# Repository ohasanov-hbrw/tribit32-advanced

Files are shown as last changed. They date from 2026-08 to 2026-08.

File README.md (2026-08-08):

# tribit32-advanced

A tri-microcontroller, overengineered GameBoy Advance clone. More value was given to the controls and the exterior look, which is cool!

## Introduction

This guide is more about the software side of the project. The 3D-Designs and the KiCad files can be found in their respective folders and be edited as needed. This project is as open source as I can make it to be, so if something is missing, message me and I will try to add it here. It would still like builds using this guide to mention me and link to this guide, so thanks in advance!

## Electronics

This section includes information about the electronics I used for the project. This project can be built in three ways: just a single board computer, just the microcontroller, or both at once. Doing both increases difficulty exponentially, so it is not really recommended and is more of a showpiece. 

### Microcontrollers and Single Board Computers

The custom PCB is laid out for an ESP32-S3-DevkitC and Raspberry Pi Zero 2W. If you can make alternatives work with adapters / custom software, you can use that too. However this project focuses more on these two specific boards. 

If you are going to be including a Raspberry Pi, you will also need to get an Arduino Pro Mini for the controller emulation. 

### Periphery

- **ILI9341 3.2inch *non-touch* SPI LCD**: 320x240 16 Bit Color, rated for 10 MHz SPI but most comfortably can run at ~67 MHz. ST7789 might work, but definitely not tested.
- **MAX98357A I2S DAC**: A pretty ok DAC + Amplifier combo. PCM5102 might work too, but these modules are cheap anyway.
- **Micro SD Adapter**: Only needed for ESP32. 
- **2x 4 ohm 20x30 mm Speakers**: Connected in series they enable rich sound.

### Power

- **5 V / 3.3 V Regulators**: Please do not use LDOs or linear regulators. These are inneficient. If just running the Raspberry Pi you can technically forego the 3.3 V Regulator and just use a 5 V one, as the Pi already has (a weak) one on board. Or even better? Use an MH-CD42 Li-Ion charger module with the onboard regulator. Less parts mean less things to solder!
- **Li-Ion Charger**: I originally used a TP4056 which did technically work fine, but after finishing the project I found out better alternatives exist that dont really have that much difference in price. Just get an MH-CD42!
### Other Components

- **6 mm Silicone Buttons**: You can also use different alternatives, the PCB should be able to support them with minimal modifications to the buttons.
- **100 ohm, 10 kohm and 100 kohm Resistors**: Values are actually not that important, something in the ballpark should work. Used mainly for pullups, resistor divider for battery monitoring...
- **Wires**: Use what you have...
- **2.54 mm male and female headers**: You can also totally do the project without any female or even any headers, but you can make pretty much everything dissasemble-able using these. 
- **BC547 NPN Transistors**: Really only needed if you are building a two-board system. 

### PCB

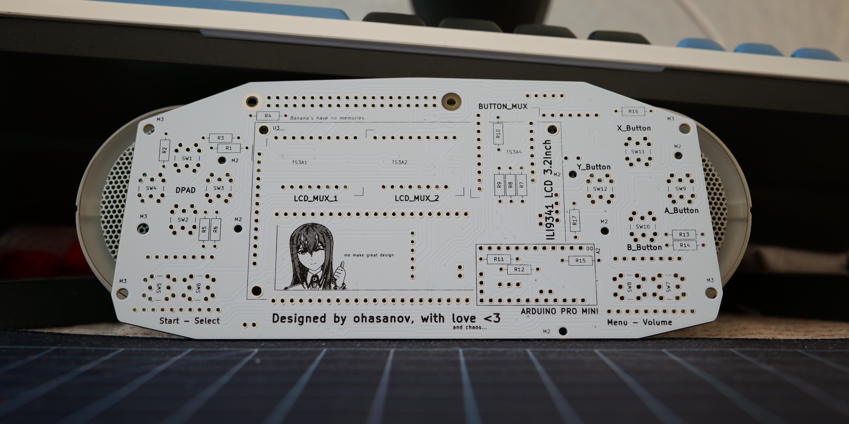
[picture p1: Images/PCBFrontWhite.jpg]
PCB Front Side

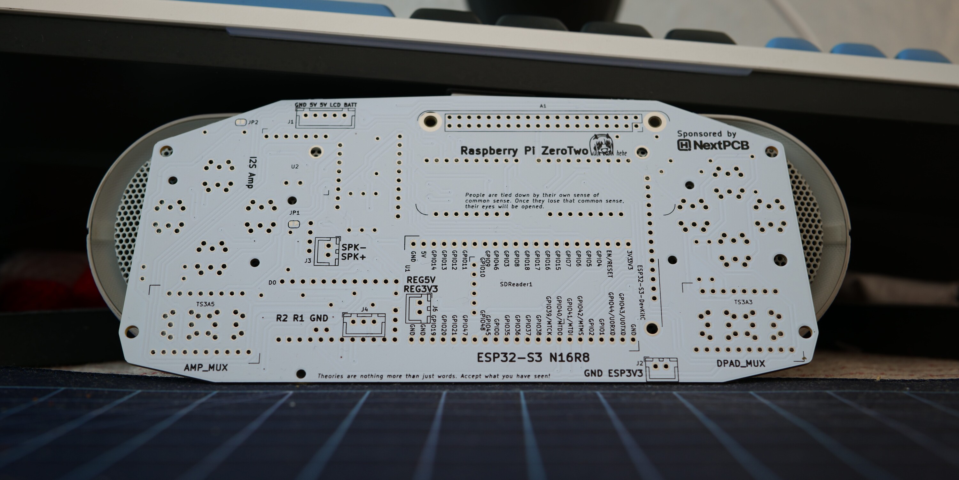
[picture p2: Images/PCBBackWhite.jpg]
PCB Back Side


This project is mainly thought out to be built with a custom PCB. Although it is technically possible to make this with normal perfboards as all used components are through hole components (no SMD components), a PCB makes the assembly process a lot faster whilst also resulting in a cleaner build. 

The PCBs for my build were manufactured by [NextPCB](https://www.nextpcb.com/). Thanks a lot for them sending over the PCBs and thus motivating me to design my own PCBs for my future projects. 

## Software Guide

This section will be divided into two subsections. Software for the ESP32 and Software for the Raspberry Pi

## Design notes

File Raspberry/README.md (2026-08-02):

# Raspberry Pi Software Setup

This folder has everything I did to a basic Raspbian OS Lite Bookworm instal to make it work with the console. Check out the individual folders for more information.

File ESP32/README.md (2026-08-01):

# retro-go
Just check https://github.com/ducalex/retro-go for installation. The guide there is good.

My config for the target esp32-s3-devkit is in this folder. There is also a compiled image, but IDK how effective that is.

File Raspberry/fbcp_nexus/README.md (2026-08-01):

# Modifications

This was also forked from [Original Modified Repo](https://github.com/The-Next-Guy/fbcp-nexus/). This fork has some modifications to fit better with my gameboy build. Modified by ohasanov.

## Original Repo

This was forked from the [Original Repo](https://github.com/juj/fbcp-ili9341). Some of the original README.md was modified. I preserved building informations, but removed stats and FAQ. To see the original information, go to the original repo. This repository implements a driver for certain SPI-based LCD displays for Raspberry Pi A, B, 2, 3, 4 and Zero. Modified by The_Next_Guy

### Tested Devices

The driver has been checked to work (at least some point in the past) on the following systems:

 - Raspberry Pi 3 Model B+ with Raspbian Stretch (GCC 6.3.0)
 - Raspberry Pi 3 Model B Rev 1.2 with Raspbian Jessie (GCC 4.9.2) and Raspbian Stretch (GCC 6.3.0)
 - Raspberry Pi Zero W with Raspbian Jessie (GCC 4.9.2) and Raspbian Stretch (GCC 6.3.0)
 - Raspberry Pi 2 Model B
 - Raspberry Pi B Rev. 2.0 (old board from Q4 2012, board revision ID 000e)
 - Raspberry Pi Zero W 2 with RetroPie

### Installation

Check the following sections to set up the driver.

##### Boot configuration

This driver does not utilize the [notro/fbtft](https://github.com/notro/fbtft) framebuffer driver, so that needs to be disabled if active. That is, if your `/boot/config.txt` file has lines that look something like `dtoverlay=pitft28r, ...`, `dtoverlay=waveshare32b, ...` or `dtoverlay=flexfb, ...`, those should be removed.

This program neither utilizes the default SPI driver, so a line such as `dtparam=spi=on` in `/boot/config.txt` should also be removed so that it will not cause conflicts.

Likewise, if you have any touch controller related dtoverlays active, such as `dtoverlay=ads7846,...` or anything that has a `penirq=` directive, those should be removed as well to avoid conflicts. It would be possible to add touch support to fbcp-ili9341 if someone wants to take a stab at it.

##### Building and running

Run in the console of your Raspberry Pi:

```bash
sudo apt-get install cmake
cd ~
git clone https://github.com/The-Next-Guy/fbcp-nexus.git
cd fbcp-nexus
mkdir build
cd build
cmake [options] ..
make -j
sudo ./fbcp-ili9341
```

Note especially the two dots `..` on the CMake line, which denote "up one directory" in this case (instead of referring to "more items go here").

See the next section to see what to input under **[options]**.

If you have been running existing `fbcp` driver, make sure to remove that e.g. via a `sudo pkill fbcp` first (while running in SSH prompt or connected to a HDMI display), these two cannot run at the same time. If `/etc/rc.local` or `/etc/init.d` contains an entry to start up `fbcp` at boot, that directive should be deleted.

##### Configuring build options

There are generally two ways to configure build options, at CMake command line, and in the file [config.h](https://github.com/juj/fbcp-ili9341/blob/master/config.h).

On the CMake command line, the following options can be configured:

###### If you have a display Add-On Hat

When using one of the displays that stack on top of the Pi that are already recognized by fbcp-ili9341, you don't need to specify the GPIO pin assignments, but fbcp-ili9341 code already has those. Pass one of the following CMake directives for the hats:

- `-DADAFRUIT_ILI9341_PITFT=ON`: If you are running on the [Adafruit 2.8" 320x240 TFT w/ Touch screen for Raspberry Pi](https://www.adafruit.com/product/1601) (or the [Adafruit PiTFT 2.2" HAT Mini Kit - 320x240 2.2" TFT - No Touch](https://www.adafruit.com/product/2315) display, which is compatible), pass this flag.
- `-DADAFRUIT_HX8357D_PITFT=ON`: If you have the [Adafruit PiTFT - Assembled 480x320 3.5" TFT+Touchscreen for Raspberry Pi](https://www.adafruit.com/product/2097) display, add this line.
- `-DFREEPLAYTECH_WAVESHARE32B=ON`: If you are running on the [Freeplay CM3 or Zero](https://www.freeplaytech.com/product/freeplay-cm3-diy-kit/) device, pass this flag. (this is not a hat, but still a preconfigured pin assignment)
- `-DWAVESHARE35B_ILI9486=ON`: If specified, targets a [Waveshare 3.5" 480x320 ILI9486](https://www.amazon.co.uk/dp/B01N48NOXI/ref=pe_3187911_185740111_TE_item) display.
- `-DTONTEC_MZ61581=ON`: If you are running on the [Tontec 3.5" 320x480 LCD Display](https://www.ebay.com/p/Tontec-3-5-Inches-Touch-Screen-for-Raspberry-Pi-Display-TFT-Monitor-480x320-LCD/1649448059) display, pass this.
- `-DPIRATE_AUDIO_ST7789_HAT=ON`: If specified, targets a [Pirate Audio 240x240, 1.3inch IPS LCD display HAT for Raspberry Pi](https://shop.pimoroni.com/collections/pirate-audio) with ST7789 display controller
- `-DWAVESHARE_ST7789VW_HAT=ON`: If specified, targets a [240x240, 1.3inch IPS LCD display HAT for Raspberry Pi](https://www.waveshare.com/1.3inch-lcd-hat.htm) with ST7789VW display controller.
- `-DWAVESHARE_ST7735S_HAT=ON`: If specified, targets a [128x128, 1.44inch LCD display HAT for Raspberry Pi](https://www.waveshare.com/1.3inch-lcd-hat.htm) with ST7735S display controller.
- `-DKEDEI_V63_MPI3501=ON`: If specified, targets a [KeDei 3.5 inch SPI TFTLCD 480*320 16bit/18bit version 6.3 2018/4/9](https://github.com/juj/fbcp-ili9341/issues/40) display with MPI3501 display controller.

###### If you wired the display to the Pi yourself

If you connected wires directly on the Pi instead of using a Hat from the above list, you will need to use the configuration directives below. In addition to specifying the display, you will also need to tell fbcp-ili9341 which GPIO pins you wired the connections to. To configure the display controller, pass one of:

- `-DILI9341=ON`: If you are running on any other generic ILI9341 display, or on Waveshare32b display that is standalone and not on the FreeplayTech CM3/Zero device, pass this flag.
- `-DILI9340=ON`: If you have a ILI9340 display, pass this directive. ILI9340 and ILI9341 chipsets are very similar, but ILI9340 doesn't support all of the features on ILI9341 and they will be disabled or downgraded.
- `-DHX8357D=ON`: If you have a HX8357D display, pass this directive.
- `-DSSD1351=ON`: If you have a SSD1351 OLED display, use this.
- `-DST7735R=ON`: If you have a ST7735R display, use this.
- `-DST7789=ON`: If you have a ST7789 display, use this.
- `-DST7789VW=ON`: If you have a ST7789VW display, use this.
- `-DST7735S=ON`: If you have a ST7735S display, use this.
- `-DILI9486=ON`: If you have a ILI9486 display, pass this directive.
- `-DILI9486L=ON`: If you have a ILI9486L display, pass this directive. Note that ILI9486 and ILI9486L are quite different, mutually incompatible controller chips, so be careful here identifying which one you have. (or just try both, should not break if you misidentified)
- `-DILI9488=ON`: If you have a ILI9488 display, pass this directive.
- `-DMPI3501=ON`: If specified, targets a display with MPI3501 display controller.

And additionally, pass the following to customize the GPIO pin assignments you used:

- `-DGPIO_TFT_DATA_CONTROL=number`: Specifies/overrides which GPIO pin to use for the Data/Control (DC) line on the 4-wire SPI communication. This pin number is specified in BCM pin numbers. If you have a 3-wire SPI display that does not have a Data/Control line, **set this value to -1**, i.e. `-DGPIO_TFT_DATA_CONTROL=-1` to tell fbcp-ili9341 to target 3-wire ("9-bit") SPI communication.
- `-DGPIO_TFT_RESET_PIN=number`: Specifies/overrides which GPIO pin to use for the display Reset line. This pin number is specified in BCM pin numbers. If omitted, it is assumed that the display does not have a Reset pin, and is always on.
- `-DGPIO_TFT_BACKLIGHT=number`: Specifies/overrides which GPIO pin to use for the display backlight line. This pin number is specified in BCM pin numbers. If omitted, it is assumed that the display does not have a GPIO-controlled backlight pin, and is always on. If setting this, also see the `#define BACKLIGHT_CONTROL` option in `config.h`.

fbcp-ili9341 always uses the hardware SPI0 port, so the MISO, MOSI, CLK and CE0 pins are always the same and cannot be changed. The MISO pin is actually not used (at the moment at least), so you can just skip connecting that one. If your display is a rogue one that ignores the chip enable line, you can omit connecting that as well, or might also be able to get away by connecting that to ground if you are hard pressed to simplify wiring (depending on the display).

###### Specifying display speed

To get good performance out of the displays, you will drive the displays far out above the rated speed specs (the rated specs yield about ~10fps depending on display). Due to this, you will need to explicitly configure the target speed you want to drive the display at, because due to manufacturing variances each display copy reaches a different maximum speed. There is no "default speed" that fbcp-ili9341 would use. Setting the speed is done via the option

- `-DSPI_BUS_CLOCK_DIVISOR=even_number`: Sets the clock divisor number which along with the Pi [core_freq=](https://www.raspberrypi.org/documentation/configuration/config-txt/overclocking.md) option in `/boot/config.txt` specifies the overall speed that the display SPI communication bus is driven at. `SPI_frequency = core_freq/divisor`. `SPI_BUS_CLOCK_DIVISOR` must be an even number. Default Pi 3B and Zero W `core_freq` is 400MHz, and generally a value `-DSPI_BUS_CLOCK_DIVISOR=6` seems to be the best that a ILI9341 display can do. Try a larger value if the display shows corrupt output, or a smaller value to get higher bandwidth. See [ili9341.h](https://github.com/juj/fbcp-ili9341/blob/master/ili9341.h#L13) and [waveshare35b.h](https://github.com/juj/fbcp-ili9341/blob/master/waveshare35b.h#L10) for data points on tuning the maximum SPI performance. Safe initial value could be something like `-DSPI_BUS_CLOCK_DIVISOR=30`.

###### Specifying the target Pi hardware

There are a couple of options to explicitly say which Pi board you want to target. These should be autodetected for you and generally are not needed, but e.g. if you are cross compiling for another Pi board from another system, or want to be explicit, you can try:

- `-DSINGLE_CORE_BOARD=ON`: Pass this option if you are running on a Pi that has only one hardware thread (Pi Model A, Pi Model B, Compute Module 1, Pi Zero/Zero W). If not present, autodetected.
- `-DARMV6Z=ON`: Pass this option to specifically optimize for ARMv6Z instruction set (Pi 1A, 1A+, 1B, 1B+, Zero, Zero W). If not present, autodetected.
- `-DARMV7A=ON`: Pass this option to specifically optimize for ARMv7-A instruction set (Pi 2B < rev 1.2). If not present, autodetected.
- `-DARMV8A=ON`: Pass this option to specifically optimize for ARMv8-A instruction set (Pi 2B >= rev. 1.2, 3B, 3B+, CM3, CM3 lite, 4B, CM4, Pi400). If not present, autodetected.

###### Specifying other build options

The following build options are general to all displays and Pi boards, they further customize the build:

- `-DBACKLIGHT_CONTROL=ON`: If set, enables fbcp-ili9341 to control the display backlight in the given backlight pin. The display will go to sleep after a period of inactivity on the screen. If not, backlight is not touched.
- `-DDISPLAY_CROPPED_INSTEAD_OF_SCALING=ON`: If set, and source video frame is larger than the SPI display video resolution, the source video is presented on the SPI display by cropping out parts of it in all directions, instead of scaling to fit.
- `-DDISPLAY_BREAK_ASPECT_RATIO_WHEN_SCALING=ON`: When scaling source video to SPI display, scaling is performed by default following aspect ratio, adding letterboxes/pillarboxes as needed. If this is set, the stretching is performed breaking aspect ratio.
- `-DSTATISTICS=number`: Specifies the level of overlay statistics to show on screen. 0: disabled, 1: enabled, 2: enabled, and show frame rate interval graph as well. Default value is 1 (enabled).
- `-DUSE_DMA_TRANSFERS=OFF`: If specified, disables using DMA transfers (at great expense of lost CPU usage). Pass this directive if DMA is giving some issues, e.g. as a troubleshooting step if something is not looking right.
- `-DDMA_TX_CHANNEL=<num>`: Specifies the DMA channel number to use for SPI send commands. Change this if you find a DMA channel conflict.
- `-DDMA_RX_CHANNEL=<num>`: Specifies the DMA channel number to use for SPI receive commands. Change this if you find a DMA channel conflict.
- `-DDISPLAY_SWAP_BGR=ON`: If this option is passed, red and blue color channels are reversed (RGB<->BGR) swap. Some displays have an opposite color panel subpixel layout that the display controller does not automatically account for, so define this if blue and red are mixed up.
- `-DDISPLAY_INVERT_COLORS=ON`: If this option is passed, pixel color value interpretation is reversed (white=0, black=31/63). Default: black=0, white=31/63. Pass this option if the display image looks like a color negative of the actual colors.
- `-DDISPLAY_ROTATE_180_DEGREES=ON`: If set, display is rotated 180 degrees. This does not affect HDMI output, only the SPI display output.
- `-DLOW_BATTERY_PIN=<num>`: Specifies a GPIO pin that can be polled to get the battery state. By default, when this is set, a low battery icon will be displayed if the pin is pulled low (see `config.h` for ways in which this can be tweaked).

###### New Build Options
- TODO

In addition to the above CMake directives, there are various defines scattered around the codebase, mostly in [config.h](https://github.com/juj/fbcp-ili9341/blob/master/config.h), that control different runtime options. Edit those directly to further tune the behavior of the program. In particular, after you have finished with the setup, you may want to build with `-DSTATISTICS=0` option in CMake configuration line.

##### Build example

Here is a full example of what to type to build and run, if you have the [Adafruit 2.8" 320x240 TFT w/ Touch screen for Raspberry Pi](https://www.adafruit.com/product/1601) with ILI9341 controller:

```bash
cd ~
sudo apt-get install cmake
git clone https://github.com/The-Next-Guy/fbcp-nexus.git
cd fbcp-nexus
mkdir build
cd build
cmake -DSPI_BUS_CLOCK_DIVISOR=6 -DADAFRUIT_ILI9341_PITFT=ON ..
make -j
sudo ./fbcp-ili9341
```

If the above does not work, try specifying `-DSPI_BUS_CLOCK_DIVISOR=8` or `=10` to make the display run a little slower, or try with `-DUSE_DMA_TRANSFERS=OFF` to troubleshoot if DMA might be the issue. If you are using another display controller than ILI9341, using a much higher value, like 30 or 40 may be needed. When changing CMake options, you can reissue the CMake directive line without having to reclone or recreate the `build` directory. However you may need to manually delete file CMakeCache.txt between changing options to avoid CMake remembering old settings.

If you want to do a full rebuild from scratch, you can `rm -rf build` to delete the build directory and recreate it for a clean rebuild from scratch. There is nothing special about the name or location of this directory, it is just my usual convention. You can also do the build in some other directory relative to the fbcp-ili9341 directory if you please.

### Extra Info

Best way to discuss the driver is to open a GitHub issue. The-Next-Guy will be monitoring any new things that pop up, pull requests, bugs, and fixes. Since this still runs just fine for RetroPie, I think its still worth maintaining. For FAQ, Tuning and more information, please check out the [Original Repo](https://github.com/juj/fbcp-ili9341).

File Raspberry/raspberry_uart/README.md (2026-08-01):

# Raspberry-UART-Controller
An uinput controller driver for the Raspberry Pi, that interfaces with an Arduino Pro Mini over the native serial port. Also draws overlays with https://github.com/The-Next-Guy/fbcp-nexus/ If something doesn't work, delete the contents of `config.prop` and rerun the software from the terminal. This starts the setup process.

### Changes made
This is a version of the whole thing that is meant to be run with a Arduino Pro mini as the Serial slave device. Instead of using axis data for the dpad, just using buttons made more sense to me. Additionally, at least the button mapping was a bit weird, which I (ohasanov) changed to suit my needs.

A (south), B (east), X (west), Y (north) is used for layout.
There are two buttons named Extra and Options. Extra is supposed to be the hotkey button for Retropie/Retroarch. Options is thought out for the whole overlay thing the original creator of this repo coded in. 

### Hotkeys (changeable under joyCheck in main.cpp):

Options + A + L + R for a sec -> reboot

Options + B + L + R for a sec -> shutdown

Options + X + L + R for a sec -> restart fbcp service

Options + B -> Battery

Options + X -> Volume (with DPAD UP DOWN to change)

Options + Y -> Brightness (with DPAD UP DOWN to change)

### Thanks
Thanks to The-Next-Guy for creating the original repo, check out https://github.com/The-Next-Guy/picotroller

### Compiling
This program requires `libevdev-dev` to be installed, which can be simply installed with
```
sudo apt-get install libevdev-dev
```

It also requires lodepng.h and lodepng.cpp to be dropped in next to the rest of the source. Ensure the SMA IDs in `shared_memory.h` are the same as the ones set in fbcp-nexus. Create a `config.prop` file next to the source, or else it will throw an error. This is also meant to be ran as a privileged app. 

To build the project, you can just run:
```
make
sudo ./joystick_emulator
```
This will take you through the setup, choose the pico monitor as the other one might be broken after my changes to the code. You can write your own too, by extending Monitor in Monitor.h. You will have to modify the main file to add the option.

If you choose the pico monitor, it will it up and strat running right away on `/dev/serial0` but you can change this by changing the `interface` property.

Once the monitor is setup, it will ask you to setup the buttons, depending on the features provided by the monitor.

Lastly, it will ask you to setup the audio device that it will be using, just enter it like it is. It could be `PCM`, `Headphone`, `HDMI`, or something else.

This whole setup can be ran from ssh, without a keyboard, provided that you have your pico or gpio pins wired up. Who knows, maybe you'll make a wifi client.

To make it start on boot, edit `/etc/rc.local` and add
```
sudo /path/to/pictroller/joystick_emulator&
```

or better yet, maybe create a systemd command to run this on startup?

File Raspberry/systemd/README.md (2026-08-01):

# SystemD Services
These files go to `/etc/systemd/system/` and are there to autostart the controller emulator and the fbcp driver. You might need to change the location of the binaries, as they are configured for my username.

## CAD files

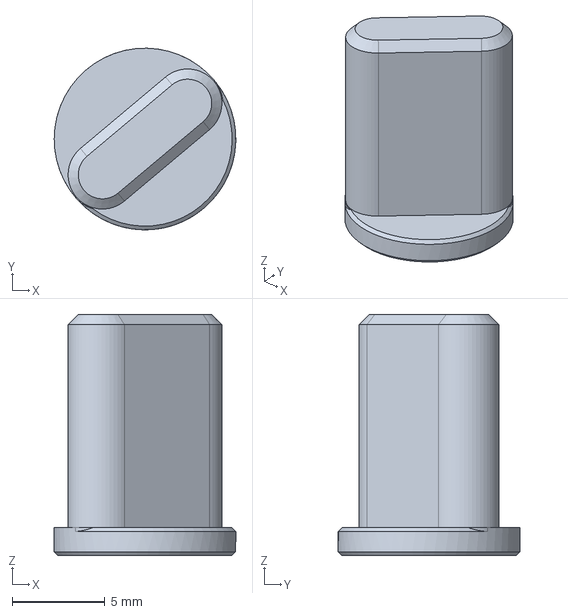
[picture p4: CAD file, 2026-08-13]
3D Files/Option Button.step
9.80 x 9.80 x 13.0 mm

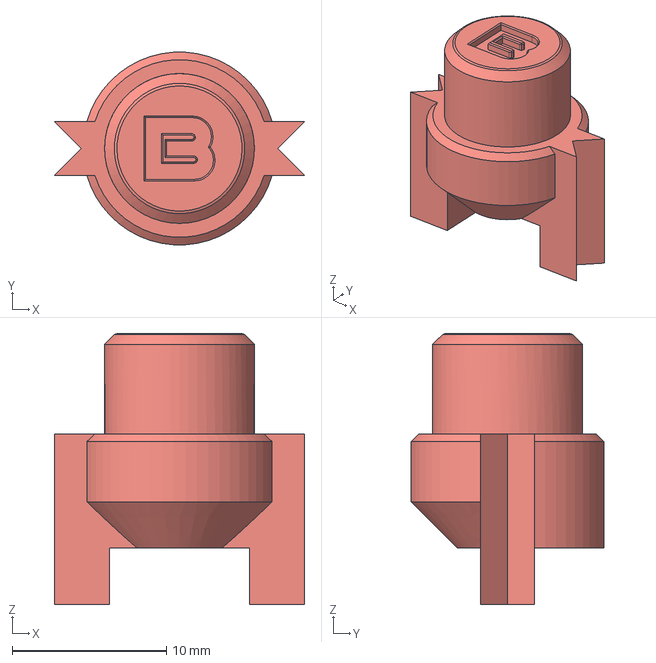
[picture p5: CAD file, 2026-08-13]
3D Files/Face Button B.step
16.2 x 12.5 x 17.6 mm

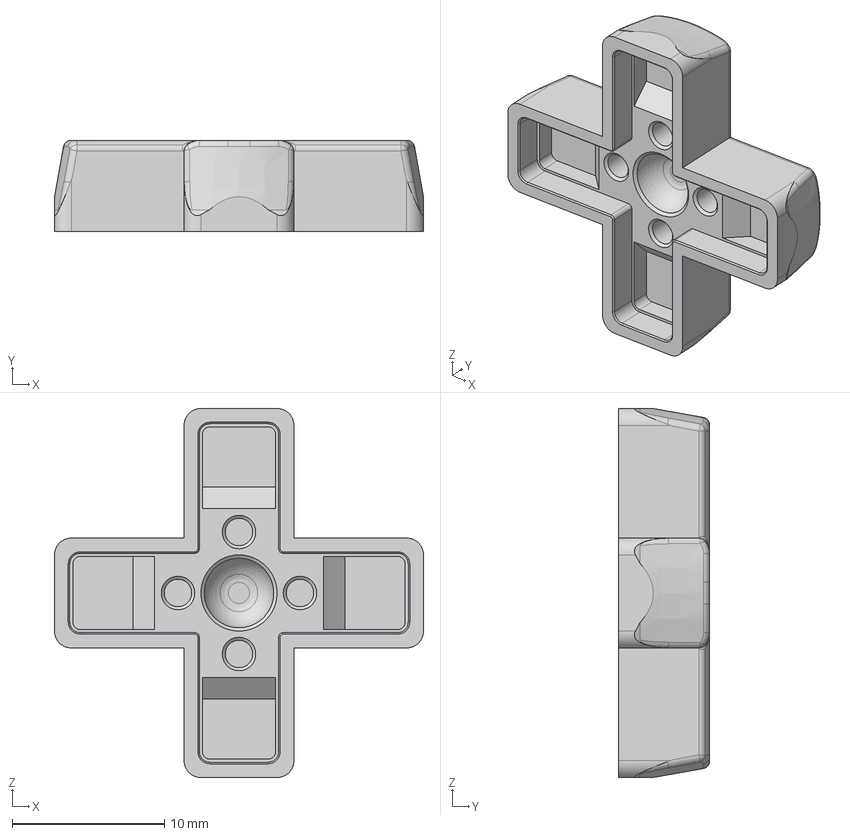
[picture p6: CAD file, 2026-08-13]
3D Files/DPADBodyTop.step
24.2 x 6.00 x 24.2 mm

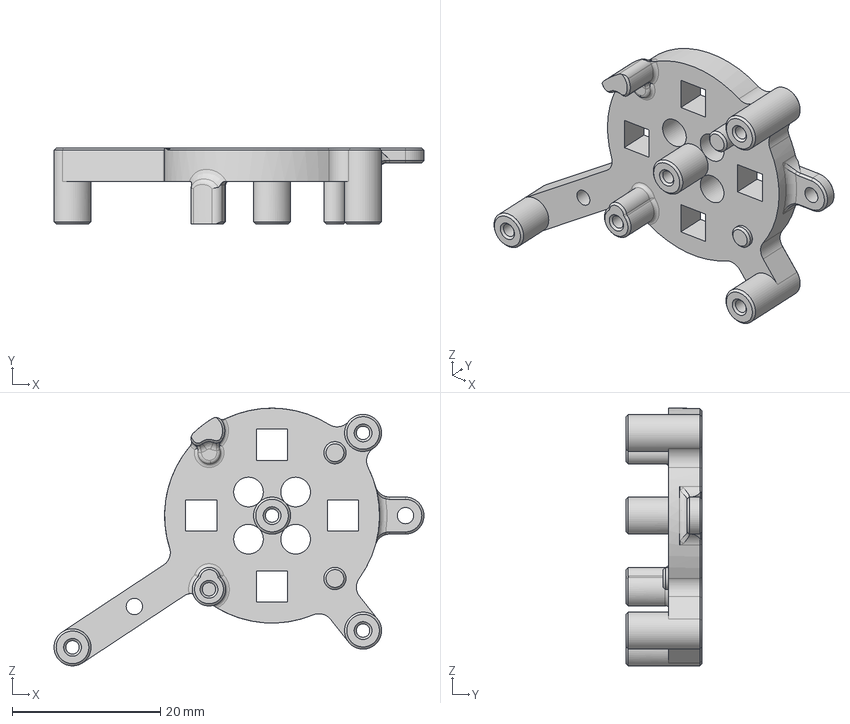
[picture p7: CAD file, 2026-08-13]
3D Files/DPADSpacer.step
49.9 x 10.3 x 34.8 mm

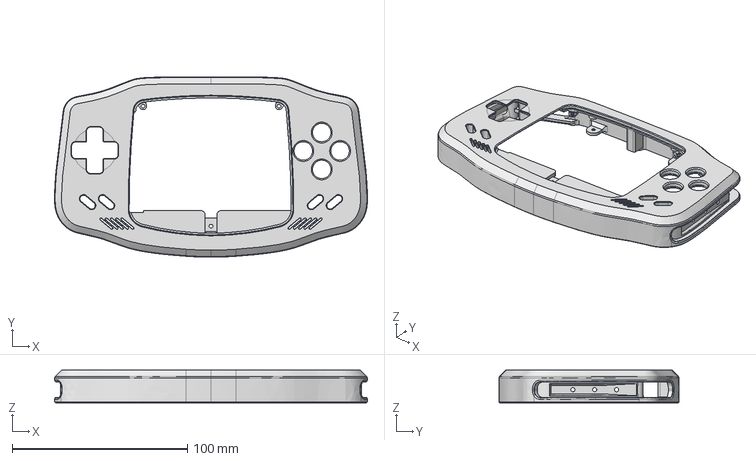
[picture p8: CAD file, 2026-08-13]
3D Files/Top Shell.step
178.5 x 102.8 x 18.7 mm

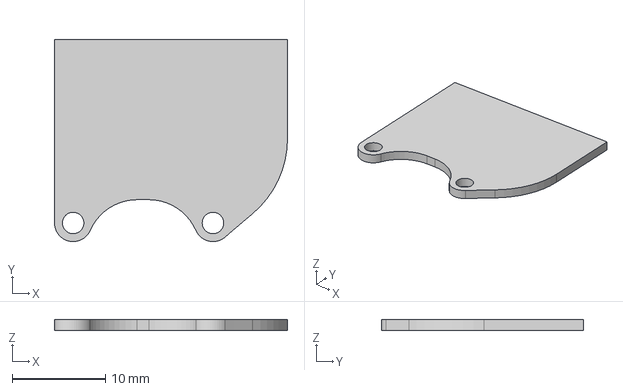
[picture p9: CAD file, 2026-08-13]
3D Files/MH-CD Holder.step
25.0 x 21.7 x 1.20 mm

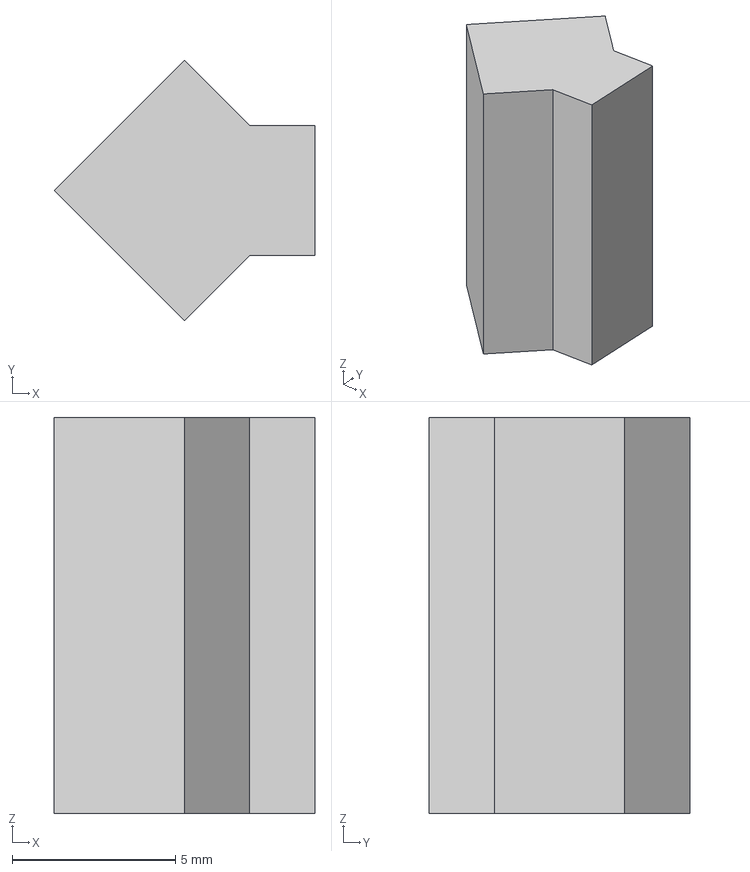
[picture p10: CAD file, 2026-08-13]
3D Files/Face Button Post Short.step
8.00 x 8.00 x 12.1 mm

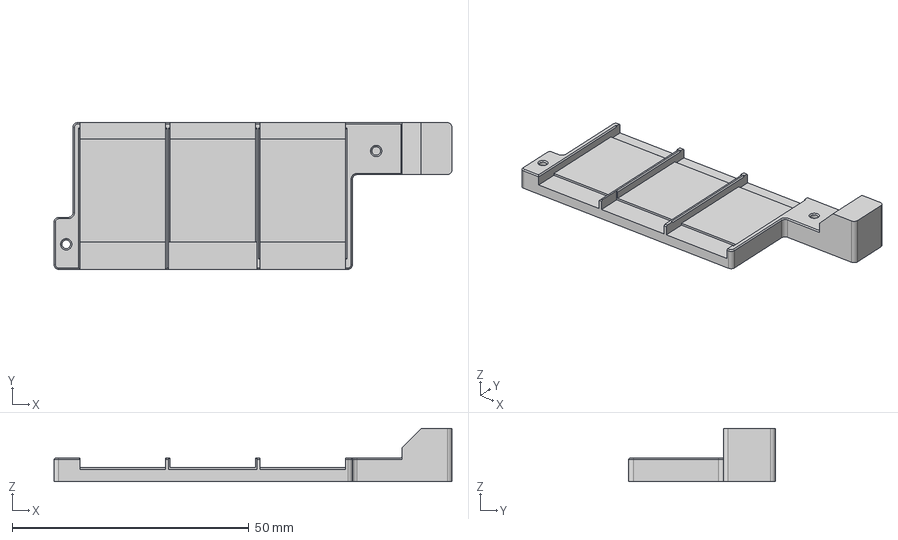
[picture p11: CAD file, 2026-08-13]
3D Files/TPS Holder Bottom.step
84.0 x 31.0 x 11.2 mm

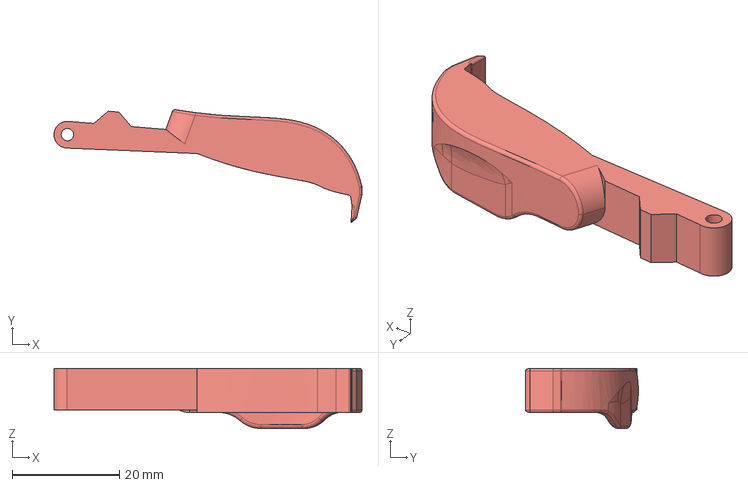
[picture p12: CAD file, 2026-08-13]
3D Files/Shoulder Button (also mirrored).step
57.3 x 21.0 x 11.2 mm

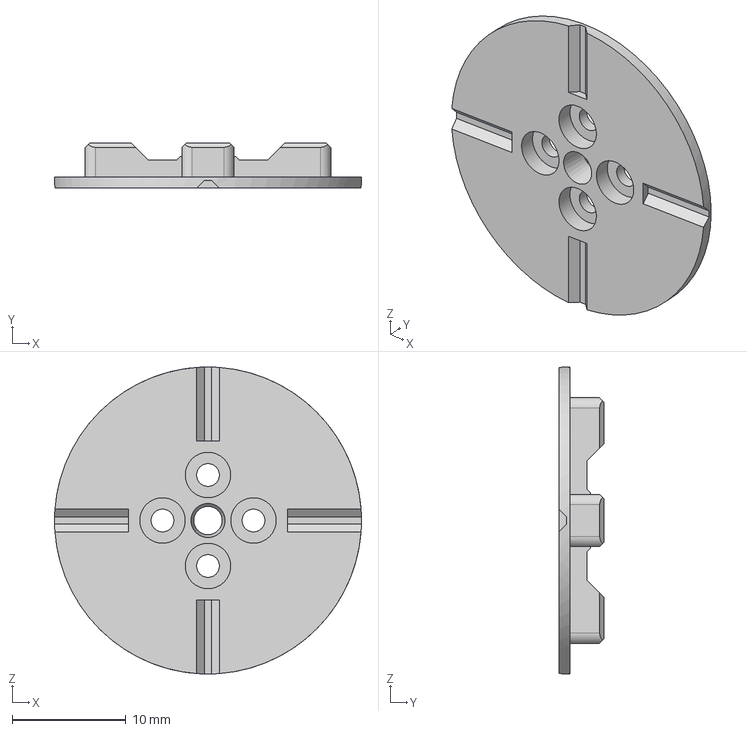
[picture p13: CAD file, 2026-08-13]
3D Files/DPADBody.step
27.0 x 4.00 x 27.0 mm

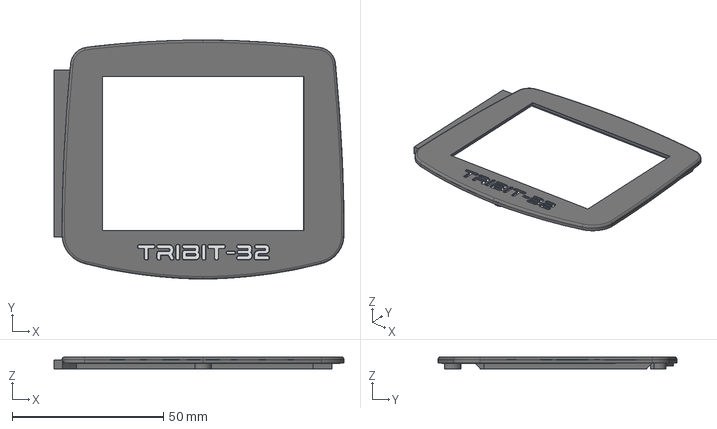
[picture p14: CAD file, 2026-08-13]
3D Files/Screen Frame.step
95.9 x 79.1 x 4.06 mm

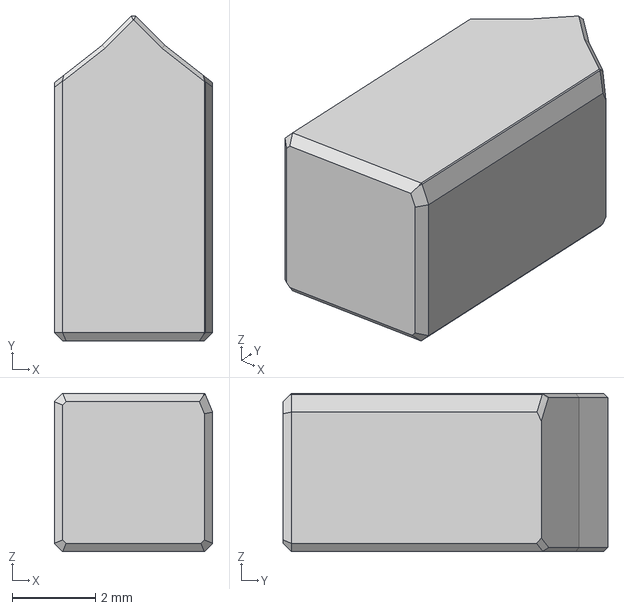
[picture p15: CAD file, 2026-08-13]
3D Files/DPADPin.step
3.80 x 7.80 x 3.80 mm

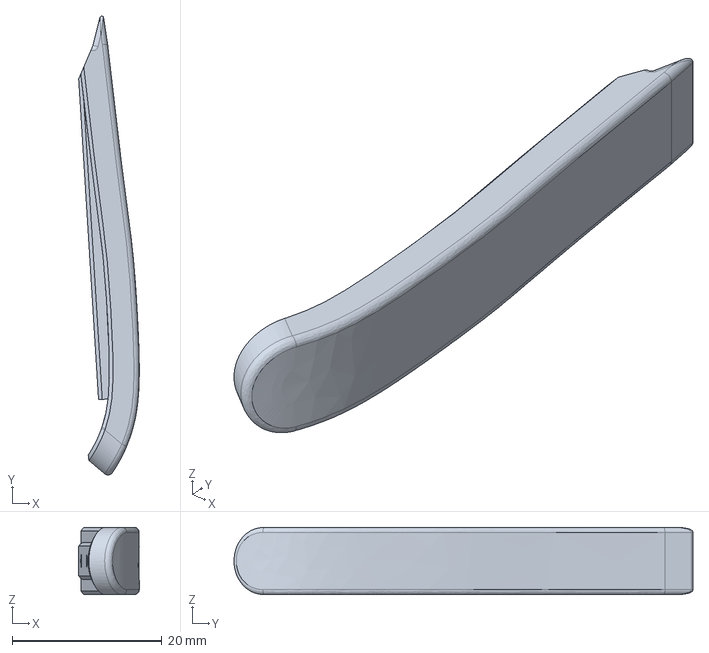
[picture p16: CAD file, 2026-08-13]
3D Files/Side Plastic (also mirrored).step
8.09 x 61.2 x 9.00 mm

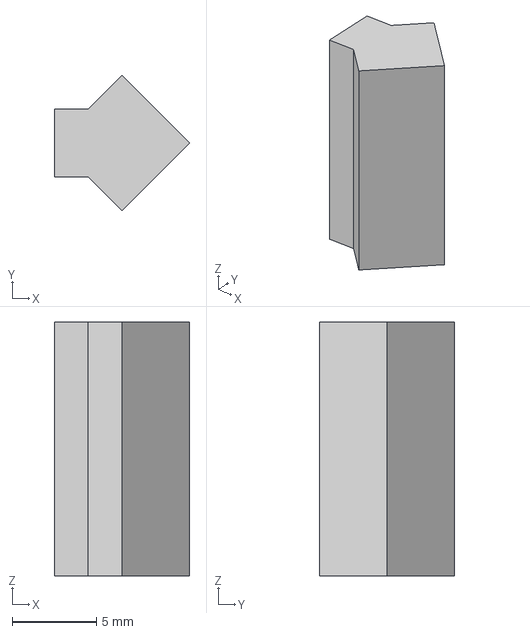
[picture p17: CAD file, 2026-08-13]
3D Files/Face Button Post Long.step
8.00 x 8.00 x 15.1 mm

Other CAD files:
3D Files/Face Button X.step
3D Files/Face Button A.step
3D Files/Top Shell Flat.stl
3D Files/TPS Holder Lid.step
3D Files/Face Button Structure.step
3D Files/Face Button Y.step
3D Files/Speaker Lid (also mirrored).step
3D Files/Switch Holder.step
3D Files/TP4056 Holder.step

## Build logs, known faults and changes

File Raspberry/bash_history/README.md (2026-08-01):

# Bash History
This is literally the complete list of commands I used for setting this up. Sadly selections for the menus are not there but it should still give an idea... More about backing up stuff than anything.

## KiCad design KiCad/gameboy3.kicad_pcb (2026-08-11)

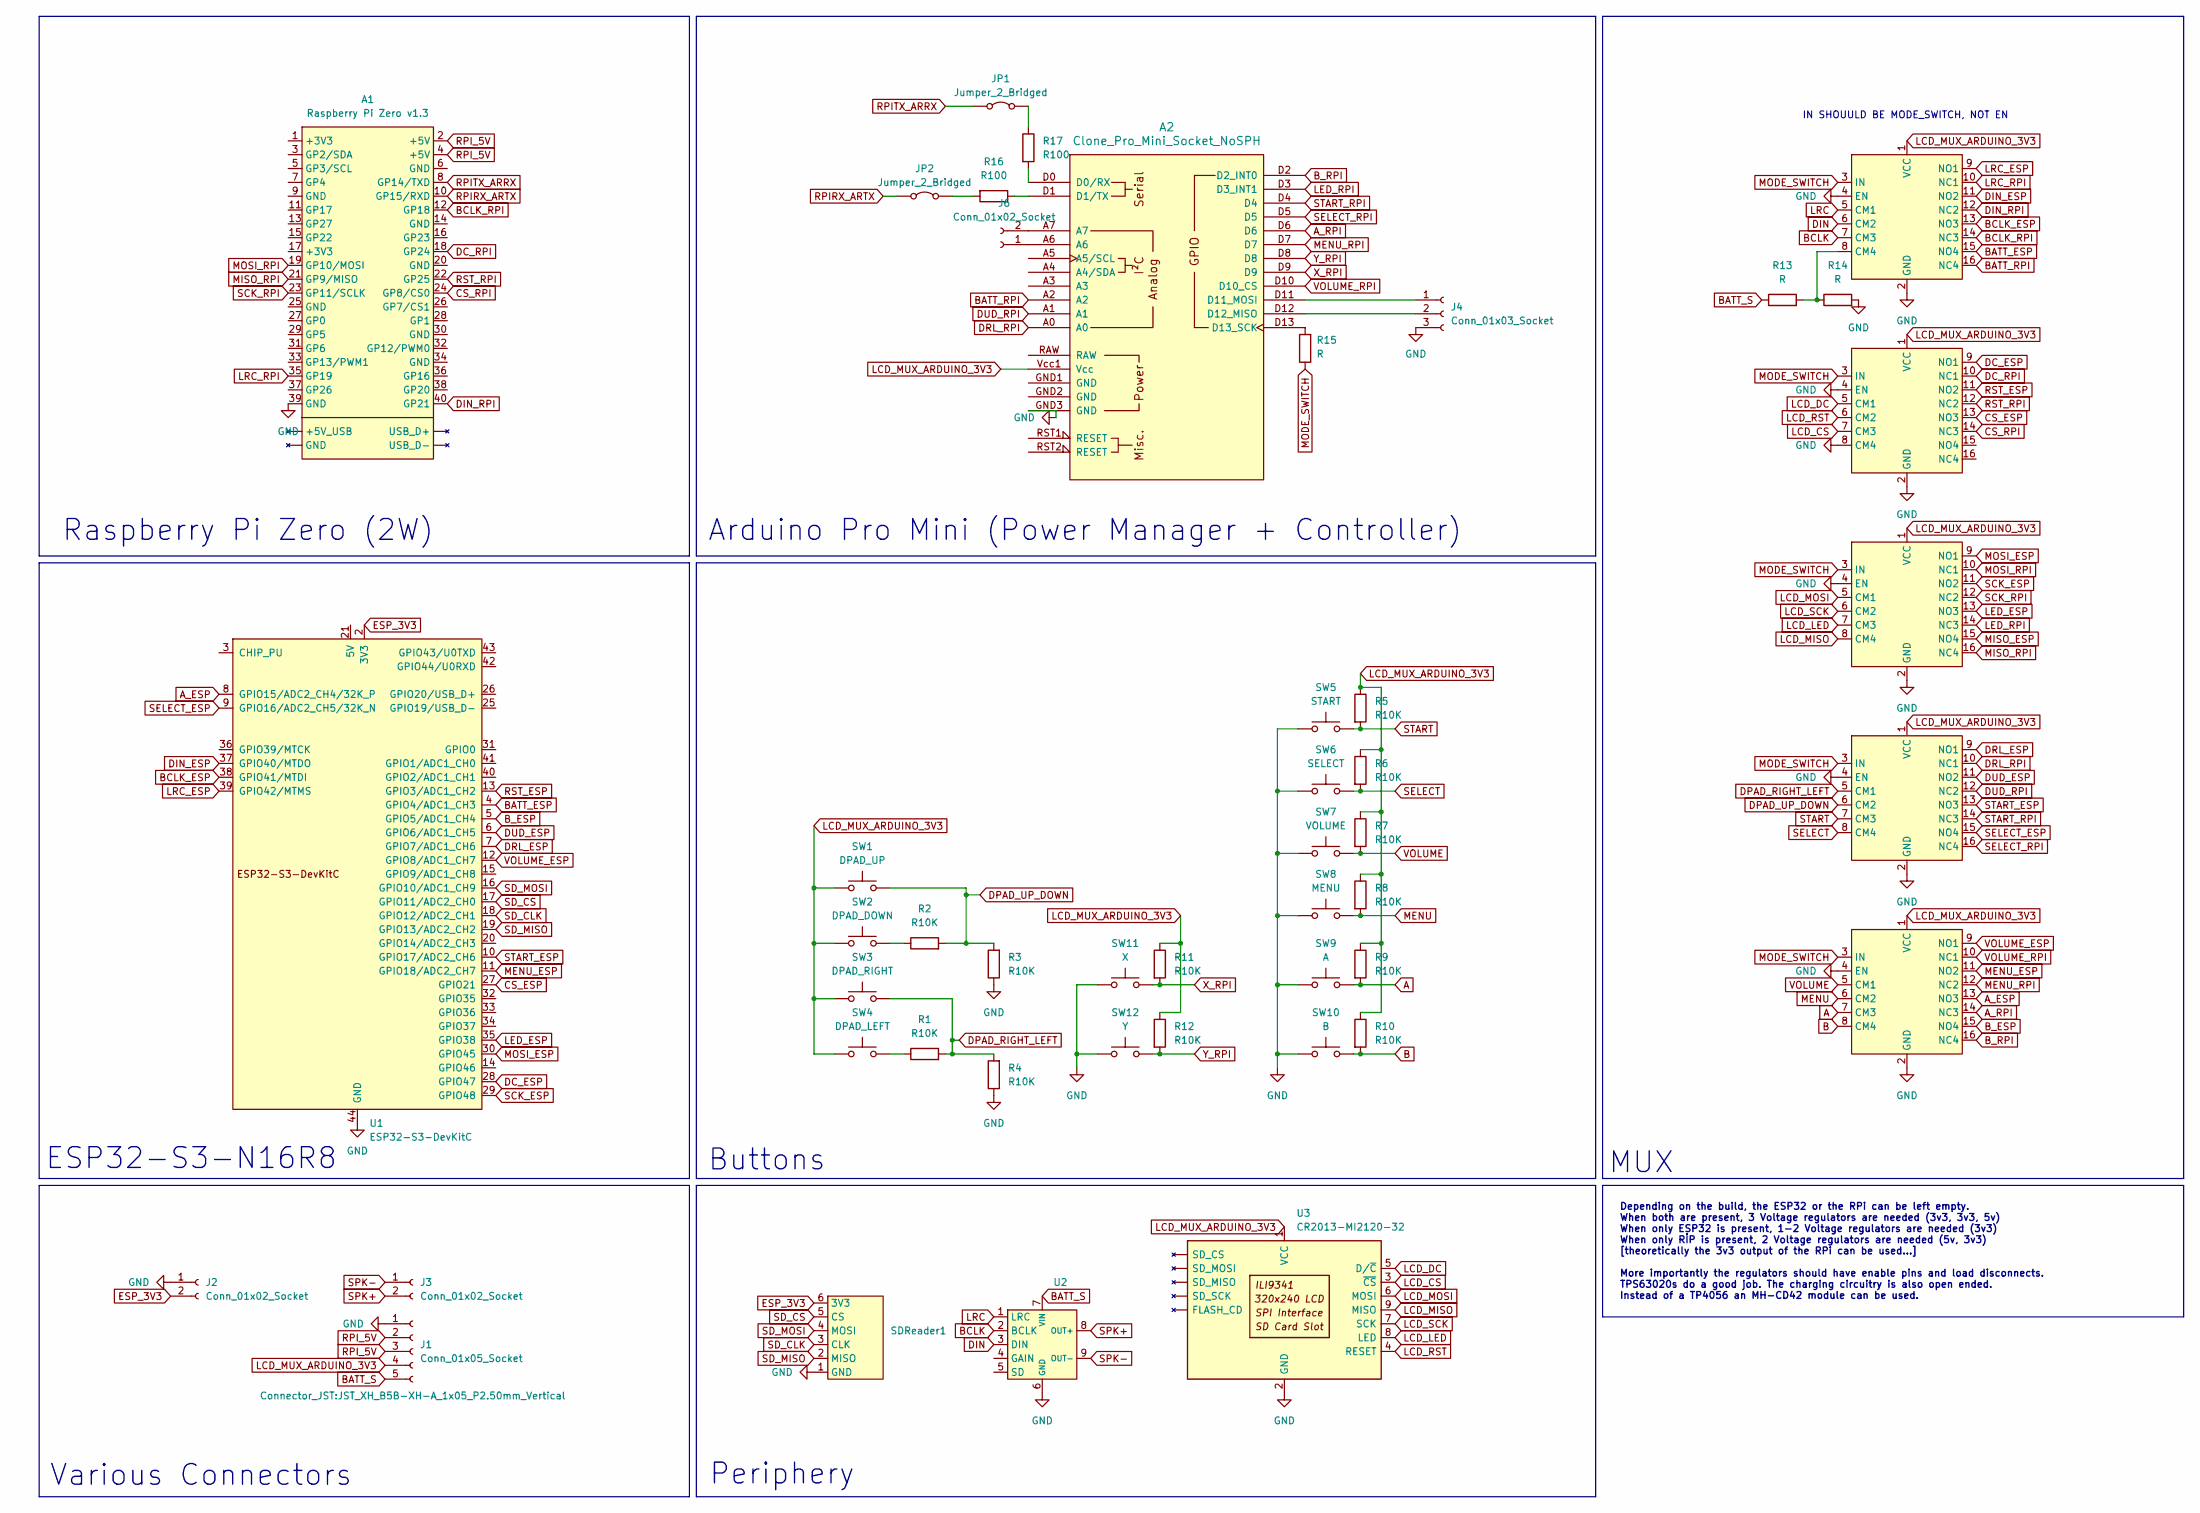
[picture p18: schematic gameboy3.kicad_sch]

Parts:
A1: Raspberry Pi Zero v1.3; Raspberry_Pi_Zero
A2: Clone_Pro_Mini_Socket_NoSPH
J1: Conn_01x05_Socket; JST_XH_B5B-XH-A_1x05_P2.50mm_Vertical
J2, J3, J6: Conn_01x02_Socket; JST_XH_B2B-XH-A_1x02_P2.50mm_Vertical
J4: Conn_01x03_Socket; JST_XH_B3B-XH-A_1x03_P2.50mm_Vertical
JP1, JP2: Jumper_2_Bridged; SolderJumper-2_P1.3mm_Open_RoundedPad1.0x1.5mm
R1, R2, R3, R4, R5, R6, R7, R8, R9, R10, R11, R12: R10K; R_Axial_DIN0207_L6.3mm_D2.5mm_P10.16mm_Horizontal
R13, R14, R15: R; R_Axial_DIN0207_L6.3mm_D2.5mm_P10.16mm_Horizontal
R16, R17: R100; R_Axial_DIN0207_L6.3mm_D2.5mm_P10.16mm_Horizontal
SDReader1: SDReader
SW1: DPAD_UP; PUSH_BUTTON
SW2: DPAD_DOWN; PUSH_BUTTON
SW3: DPAD_RIGHT; PUSH_BUTTON
SW4: DPAD_LEFT; PUSH_BUTTON
SW5: START; PUSH_BUTTON
SW6: SELECT; PUSH_BUTTON
SW7: VOLUME; PUSH_BUTTON
SW8: MENU; PUSH_BUTTON
SW9: A; PUSH_BUTTON
SW10: B; PUSH_BUTTON
SW11: X; PUSH_BUTTON
SW12: Y; PUSH_BUTTON
TS3A1, TS3A2, TS3A3, TS3A4, TS3A5: TS3A5018_Module
U1: ESP32-S3-DevKitC
U2: MAX_I2S
U3: CR2013-MI2120-32

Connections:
A: R9.2, SW9.2, TS3A4.7 (CM3)
A_ESP: TS3A4.13 (NO3), U1.8 (GPIO15/ADC2_CH4/32K_P)
A_RPI: A2.D6, TS3A4.14 (NC3)
B: R10.2, SW10.2, TS3A4.8 (CM4)
BATT_ESP: TS3A5.15 (NO4), U1.4 (GPIO4/ADC1_CH3)
BATT_RPI: A2.A2, TS3A5.16 (NC4)
BATT_S: J1.5, R13.1, U2.7 (VIN)
BCLK: TS3A5.7 (CM3), U2.2 (BCLK)
BCLK_ESP: TS3A5.13 (NO3), U1.38 (GPIO41/MTDI)
BCLK_RPI: A1.12 (GP18), TS3A5.14 (NC3)
B_ESP: TS3A4.15 (NO4), U1.5 (GPIO5/ADC1_CH4)
B_RPI: A2.D2 (D2_INT0), TS3A4.16 (NC4)
CS_ESP: TS3A2.13 (NO3), U1.27 (GPIO21)
CS_RPI: A1.24 (GP8/CS0), TS3A2.14 (NC3)
DC_ESP: TS3A2.9 (NO1), U1.28 (GPIO47)
DC_RPI: A1.18 (GP24), TS3A2.10 (NC1)
DIN: TS3A5.6 (CM2), U2.3 (DIN)
DIN_ESP: TS3A5.11 (NO2), U1.37 (GPIO40/MTDO)
DIN_RPI: A1.40 (GP21), TS3A5.12 (NC2)
DPAD_RIGHT_LEFT: R1.2, R4.2, SW3.2, TS3A3.5 (CM1)
DPAD_UP_DOWN: R2.2, R3.2, SW1.2, TS3A3.6 (CM2)
DRL_ESP: TS3A3.9 (NO1), U1.7 (GPIO7/ADC1_CH6)
DRL_RPI: A2.A0, TS3A3.10 (NC1)
DUD_ESP: TS3A3.11 (NO2), U1.6 (GPIO6/ADC1_CH5)
DUD_RPI: A2.A1, TS3A3.12 (NC2)
ESP_3V3: J2.2, SDReader1.6 (3V3), U1.1 (3V3), U1.2 (3V3)
GND: A1.39 (GND), A2.GND3 (GND), J1.1, J2.1, J4.3, R3.1, R4.1, R14.2, SDReader1.1 (GND), SW5.1, SW6.1, SW7.1, SW8.1, SW9.1, SW10.1, SW11.1, SW12.1, TS3A1.2 (GND), TS3A1.4 (EN), TS3A2.2 (GND), TS3A2.4 (EN), TS3A2.8 (CM4), TS3A3.2 (GND), TS3A3.4 (EN), TS3A4.2 (GND), TS3A4.4 (EN), TS3A5.2 (GND), TS3A5.4 (EN), U1.22 (GND), U1.23 (GND), U1.24 (GND), U1.44 (GND), U2.6 (GND), U3.2 (GND)
LCD_CS: TS3A2.7 (CM3), U3.3 (~CS)
LCD_DC: TS3A2.5 (CM1), U3.5 (D/~C)
LCD_LED: TS3A1.7 (CM3), U3.8 (LED)
LCD_MISO: TS3A1.8 (CM4), U3.9 (MISO)
LCD_MOSI: TS3A1.5 (CM1), U3.6 (MOSI)
LCD_MUX_ARDUINO_3V3: A2.Vcc1 (Vcc), J1.4, R5.1, R6.1, R7.1, R8.1, R9.1, R10.1, R11.1, R12.1, SW1.1, SW2.1, SW3.1, SW4.1, TS3A1.1 (VCC), TS3A2.1 (VCC), TS3A3.1 (VCC), TS3A4.1 (VCC), TS3A5.1 (VCC), U3.1 (VCC)
LCD_RST: TS3A2.6 (CM2), U3.4 (RESET)
LCD_SCK: TS3A1.6 (CM2), U3.7 (SCK)
LED_ESP: TS3A1.13 (NO3), U1.35 (GPIO38)
LED_RPI: A2.D3 (D3_INT1), TS3A1.14 (NC3)
LRC: TS3A5.5 (CM1), U2.1 (LRC)
LRC_ESP: TS3A5.9 (NO1), U1.39 (GPIO42/MTMS)
LRC_RPI: A1.35 (GP19), TS3A5.10 (NC1)
MENU: R8.2, SW8.2, TS3A4.6 (CM2)
MENU_ESP: TS3A4.11 (NO2), U1.11 (GPIO18/ADC2_CH7)
MENU_RPI: A2.D7, TS3A4.12 (NC2)
MISO_ESP: TS3A1.15 (NO4)
MISO_RPI: A1.21 (GP9/MISO), TS3A1.16 (NC4)
MODE_SWITCH: R15.1, TS3A1.3 (IN), TS3A2.3 (IN), TS3A3.3 (IN), TS3A4.3 (IN), TS3A5.3 (IN)
MOSI_ESP: TS3A1.9 (NO1), U1.30 (GPIO45)
MOSI_RPI: A1.19 (GP10/MOSI), TS3A1.10 (NC1)
unnamed: A2.D0 (D0/RX), R17.2
unnamed: A2.D1 (D1/TX), R16.1
unnamed: A2.D11 (D11_MOSI), J4.1
unnamed: A2.D12 (D12_MISO), J4.2
unnamed: A2.D13 (D13_SCK), R15.2
unnamed: A2.A6, J6.1
unnamed: A2.A7, J6.2
unnamed: JP1.2 (B), R17.1
unnamed: JP2.2 (B), R16.2
unnamed: R1.1, SW4.2
unnamed: R2.1, SW2.2
unnamed: R13.2, R14.1, TS3A5.8 (CM4)
RPIRX_ARTX: A1.10 (GP15/RXD), JP2.1 (A)
RPITX_ARRX: A1.8 (GP14/TXD), JP1.1 (A)
RPI_5V: A1.2 (+5V), A1.4 (+5V), J1.2, J1.3
RST_ESP: TS3A2.11 (NO2), U1.13 (GPIO3/ADC1_CH2)
RST_RPI: A1.22 (GP25), TS3A2.12 (NC2)
SCK_ESP: TS3A1.11 (NO2), U1.29 (GPIO48)
SCK_RPI: A1.23 (GP11/SCLK), TS3A1.12 (NC2)
SD_CLK: SDReader1.3 (CLK), U1.18 (GPIO12/ADC2_CH1)
SD_CS: SDReader1.5 (CS), U1.17 (GPIO11/ADC2_CH0)
SD_MISO: SDReader1.2 (MISO), U1.19 (GPIO13/ADC2_CH2)
SD_MOSI: SDReader1.4 (MOSI), U1.16 (GPIO10/ADC1_CH9)
SELECT: R6.2, SW6.2, TS3A3.8 (CM4)
SELECT_ESP: TS3A3.15 (NO4), U1.9 (GPIO16/ADC2_CH5/32K_N)
SELECT_RPI: A2.D5, TS3A3.16 (NC4)
SPK+: J3.2, U2.8 (OUT+)
SPK-: J3.1, U2.9 (OUT-)
START: R5.2, SW5.2, TS3A3.7 (CM3)
START_ESP: TS3A3.13 (NO3), U1.10 (GPIO17/ADC2_CH6)
START_RPI: A2.D4, TS3A3.14 (NC3)
VOLUME: R7.2, SW7.2, TS3A4.5 (CM1)
VOLUME_ESP: TS3A4.9 (NO1), U1.12 (GPIO8/ADC1_CH7)
VOLUME_RPI: A2.D10 (D10_CS), TS3A4.10 (NC1)
X_RPI: A2.D9, R11.2, SW11.2
Y_RPI: A2.D8, R12.2, SW12.2

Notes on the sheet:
Depending on the build, the ESP32 or the RPi can be left empty. When both are present, 3 Voltage regulators are needed (3v3, 3v3, 5v) When only ESP32 is present, 1-2 Voltage regulators are needed (3v3) When only RİP is present, 2 Voltage regulators are needed (5v, 3v3) [theoretically the 3v3 output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
Various Connectors
Periphery
Buttons
IN SHOUULD BE MODE_SWITCH, NOT EN
ESP32-S3-N16R8
Raspberry Pi Zero (2W)
Arduino Pro Mini (Power Manager + Controller)
MUX

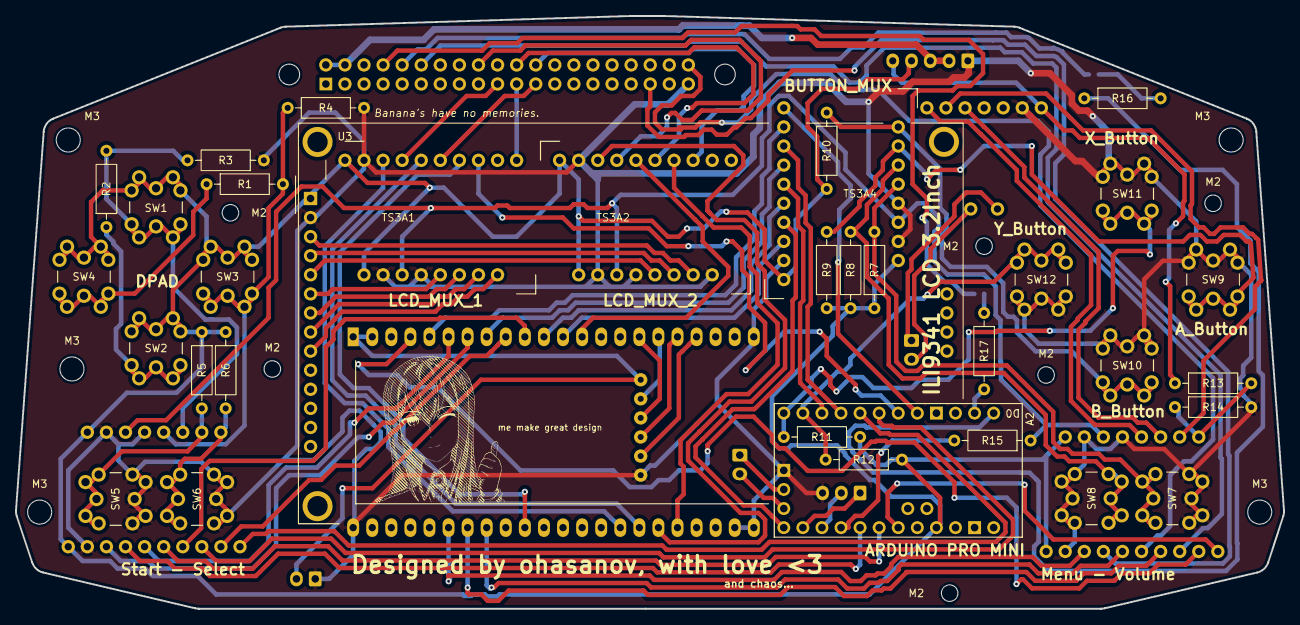
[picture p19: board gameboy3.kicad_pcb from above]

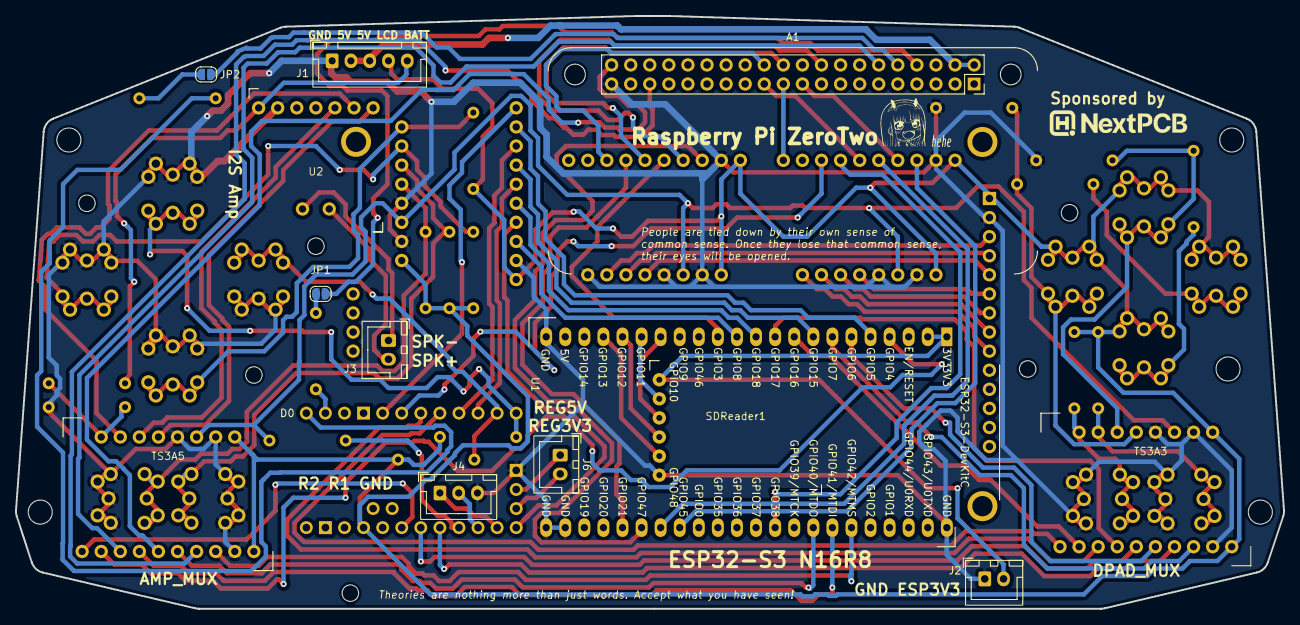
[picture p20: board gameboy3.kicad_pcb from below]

Board: 2 copper layers, 168.8 x 78.9 mm, 61 parts (15 on the bottom side), 83 nets.

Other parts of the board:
M2, M2#2, M2#3, M2#4, M2#5, M2#6: MountingHole_2.2mm_M2_DIN965
M3, M3#2, M3#3, M3#4, M3#5: MountingHole_3.2mm_M3_DIN965
Sponsored by: LOGO
hehe: LOGO
me make great design: LOGO

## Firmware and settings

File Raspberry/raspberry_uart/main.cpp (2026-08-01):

#include <iostream>
#include <cstdio>
#include <thread>
#include <fcntl.h>
#include <unistd.h>
#include <libgen.h>
#include <cstring>
#include <string>
#include <sys/reboot.h>

#include "overlay.h"
#include "pico_monitor.h"
#include "gpio_monitor.h"
#include "controller.h"
#include "GPIO.h"
#include "properties.h"

#define VERSION "0.1"

#define OVERLAY_TIMEOUT 5
#define STATUS_TIMEOUT 10
#define FAN_MIN_VALUE 125

#define FAN_STEP_SIZE 5
#define BACK_STEP_SIZE 5

#define AXIS_DEADZONE 100
#define RESISTOR_RATIO 2
#define VREF_ADC 3.3
#define VOFF 0.1

#define OVERLAY_BATTERY 0
#define OVERLAY_BRIGHTNESS 4
#define OVERLAY_FAN 2
#define OVERLAY_VOLUME 1
#define OVERLAY_CLOSED -1

#define DEBUG_GPIO_OVERLAY false

using String = std::string;

int VOLUME_STEP_SIZE = 1, VOLUME_MIN = 0, VOLUME_MAX = 1;
int SELECT_BUTTON, START_BUTTON, L_BUTTON, R_BUTTON, A_BUTTON, B_BUTTON, X_BUTTON, Y_BUTTON, EXTRA_BUTTON, OPTIONS_BUTTON , DPAD_UP, DPAD_DOWN, DPAD_LEFT, DPAD_RIGHT;
bool joyCheck(ControllerData[], int);
std::string getLocalFile(const std::string& filename);

Monitor* monitor = nullptr;
ControllerManager manager(joyCheck);
OverlayManager overlay;
GPIO gpio;

volatile int overlay_counter = 0, fanCounter = 0, special_counter = 0;
int last_vol, overlay_id = -1, overlay_dir;
std::string audDevice;

void controllerLoop() {
    manager.loop();
}

void picoProcess(int data) {
	std::cout << "Battery Value: " << manager.batteryValue << std::endl;
}

float batt_diffs[11] = {4.05, 4.00, 3.95, 3.92, 3.87, 3.82, 3.79, 3.75, 3.72, 3.65, 3.20};
int   batt_percs[11] = {100, 90, 80, 70, 60, 50, 40, 30, 20, 10, 1};

int getBatteryPercentage(float voltage) {
	int perc = 0;
	int diff_index = 0;
    for(int i = 0; i < 11; i++) {
		if(voltage > batt_diffs[i]) {
			perc = batt_percs[i];
			diff_index = i;
			break;
		}
	}
	
	if(perc == 0 || perc == 100) return perc;
	
	float delta = (voltage - batt_diffs[diff_index]) / (batt_diffs[diff_index - 1] - batt_diffs[diff_index]);
	perc += (int)(delta * 10);
	
	return perc;
}

void drawVolumeOverlay(int dir, int value) {
	overlay.drawPNG(getLocalFile("assets/overlay_rp.png").c_str(), 0, 0);
	
	float ratio = (float)(value - VOLUME_MIN) / (VOLUME_MAX - VOLUME_MIN);
	float percent = ratio * 100;
	
	if(percent > 70){
		overlay.drawPNG(getLocalFile("assets/volume_full.png").c_str(), 289, 39);
	} else if(percent > 40){
		overlay.drawPNG(getLocalFile("assets/volume_med.png").c_str(), 289, 39);
	}  else if(percent > 1){
		overlay.drawPNG(getLocalFile("assets/volume_low.png").c_str(), 289, 39);
	} else {
		overlay.drawPNG(getLocalFile("assets/volume_mute.png").c_str(), 289, 39);
	}
	
	std::string dStr = std::to_string((int)(percent));
	int xOff = 293;
	
	int strLen = dStr.length();
	if(strLen == 1) xOff += 5;
	if(strLen == 2) xOff += 2;
	
	overlay.drawString(dStr.c_str(), xOff, 190, 0xFFFF, 0xF0);
	
	int h = (118 * ratio);
	
	overlay.drawRect(290, 65, 22, 120, 0xFFFF, 0xFF);
	overlay.fillRect(291, 66 + (118 - h), 20, h, 0xFFFF, 0xFF);
}

void drawFanOverlay(int value, int change) {
	overlay.drawPNG(getLocalFile("assets/overlay_rp.png").c_str(), 0, 0);
	
	fanCounter = (fanCounter+1) % 8;
	int fanFrame = fanCounter;
	
	std::string path = getLocalFile("assets/fan_" + std::to_string(fanFrame) + ".png");
	overlay.drawPNG(path.c_str(), 289, 39);
	
	value -= FAN_MIN_VALUE;
	if(value < 0) value = 0;
	
	float ratio = (float)value / (255 - FAN_MIN_VALUE);
	float percent = ratio * 100;
	
	std::string dStr = std::to_string((int)(percent));
	int xOff = 293;
	
	int strLen = dStr.length();
	if(strLen == 1) xOff += 5;
	if(strLen == 2) xOff += 2;
	
	overlay.drawString(dStr.c_str(), xOff, 190, 0xFFFF, 0xF0);
	
	int h = (118 * ratio);
	
	overlay.drawRect(290, 65, 22, 120, 0xFFFF, 0xFF);
	overlay.fillRect(291, 66 + (118 - h), 20, h, 0xFFFF, 0xFF);
}

void drawBacklightOverlay(int value, int change) {
	overlay.drawPNG(getLocalFile("assets/overlay_rp.png").c_str(), 0, 0);
	
	if(value < 0) value = 0;
	
	float ratio = (float)value / 255;
	float percent = ratio * 100;
	
	if(percent > 75){
		overlay.drawPNG(getLocalFile("assets/brightness_full.png").c_str(), 289, 39);
	} else if(percent > 25){
		overlay.drawPNG(getLocalFile("assets/brightness_half.png").c_str(), 289, 39);
	} else {
		overlay.drawPNG(getLocalFile("assets/brightness_none.png").c_str(), 289, 39);
	}
	
	std::string dStr = std::to_string((int)(percent));
	int xOff = 293;
	
	int strLen = dStr.length();
	if(strLen == 1) xOff += 5;
	if(strLen == 2) xOff += 2;
	
	overlay.drawString(dStr.c_str(), xOff, 190, 0xFFFF, 0xF0);
	
	int h = (118 * ratio);
	
	overlay.drawRect(290, 65, 22, 120, 0xFFFF, 0xFF);
	overlay.fillRect(291, 66 + (118 - h), 20, h, 0xFFFF, 0xFF);
}

float batteryVoltage = 0;

int adcSamples[20] = {0};
int adcSampleIndex = 0;
int adcSampleCount = 0;
int adcTotalSum = 0;

void drawBatteryOverlay(int value) {
	overlay.drawPNG(getLocalFile("assets/battery_overlay.png").c_str(), 0, 0);

        adcTotalSum -= adcSamples[adcSampleIndex];
        adcSamples[adcSampleIndex] = value;
        adcTotalSum += value;

        adcSampleIndex = (adcSampleIndex + 1) % 20;
        if (adcSampleCount < 20) {
            adcSampleCount++;
        }

        float averageValue = (float)adcTotalSum / adcSampleCount;
        float voltage = (((averageValue / (float)1023) * VREF_ADC) + VOFF) * RESISTOR_RATIO;


	//float voltage = (((value / (float)1023) * VREF_ADC) + VOFF) * RESISTOR_RATIO;
	int percent = getBatteryPercentage(voltage);
	batteryVoltage = voltage;
	char buffer[20];
    sprintf(buffer, "%d%% (%.3fv)", percent, voltage);
	
	std::string dStr = std::string(buffer) + (voltage > 4.3 ? " Charging" : " Battery");
	int xOff = (320 - overlay.getStringWidth(dStr.c_str())) / 2;
	//xOff += (3 - dStr.length()) * 3;
	overlay.drawString(dStr.c_str(), xOff, 24, 0xFFFF, 0xFF);
	
	
	int width = (float)232 / 100 * percent;
	overlay.drawRect(43, 2, 234, 16, 0xFFFF, 0xFF);
	overlay.fillRect(44 + (232 - width), 3, width, 14, 0xFFFF, 0xFF);
}

void render_pin_states(){
	int size = 10;
	int xOff = 75;
	int yOff = 20;
	
	overlay.fillRect(320 - (size * 2 + xOff), yOff, size * 2, size * 20, 0xFFFF, 0xFF);
	for(int i = 0; i < 40; i++){
		int x = i < 20 ? 320 - (size * 2 + xOff) : 320 - (size + xOff);
		int y = (i % 20) * size + yOff;
		
		int textX = i < 20 ? 320 - ((size * 8) + xOff - 6) : 320 - (xOff - 1);
		
		bool filled = false;
		bool dir = false;
		bool ioPin = false;
		
		std::string func = "";
		if(HEADER_IO_PINS[i] > 0){
			filled = gpio.readPin(HEADER_IO_PINS[i]);
			dir = gpio.getPinDirection(HEADER_IO_PINS[i]);
		}
		
		int color = 0;
		switch(HEADER_IO_PINS[i]){
			case -4: //DNC Pin
			color = 0xFC00;
			func = "DNC";
			break;
			
			case -3: //5v Pin
			color = 0xFA00;
			func = "5V";
			break;
			
			case -2: //3.3v Pin
			color = 0xF800;
			func = "3V3";
			break;
			
			case -1: //GND Pin
			color = 0x0000;
			func = "GND";
			break;
			
			default: //GND Pin
			color = 0x07E0;
			func = std::to_string(HEADER_IO_PINS[i]);
			ioPin = true;
			break;
		}
		
		if(filled){
			overlay.fillRect(x, y, size, size, color, 0xFF);
		} else {
			overlay.drawRect(x, y, size, size, color, 0xFF);
		}
		while(func.length() < 3) {
			if(i < 20){
				func.insert(0, " ");
			} else {
				func.append(" ");
			}
		}
		
		std::string pinData;
		
		if(ioPin){
			pinData.append(dir ? "Out:" : "In: ");
			pinData.append(filled ? "1" : "0");
		} else {
			pinData.append("     ");
		}
		
		if(i < 20){
			func.append(" ");
			func.append(pinData);
		} else {
			func.insert(0, " ");
			func.insert(0, pinData);
		}
		
		overlay.drawString(func.c_str(), textX, y, 0xFFFF, 0xFF);
	}
}

void controlBrightness(int value) {
	if(value > AXIS_DEADZONE) { //Adjust Down
		manager.monitorRequest(7, manager.backlightValue - BACK_STEP_SIZE);
	} else if(value < -AXIS_DEADZONE) { //Adjust Up
		manager.monitorRequest(7, manager.backlightValue + BACK_STEP_SIZE);
	}
}

void controlFan(int value) {
	if(value > AXIS_DEADZONE) { //Adjust Down
		manager.monitorRequest(5, manager.fanValue - FAN_STEP_SIZE);
	} else if(value < -AXIS_DEADZONE) { //Adjust Up
		manager.monitorRequest(5, manager.fanValue + FAN_STEP_SIZE);
	}
}

std::string removeSubstring(const std::string& str, const std::string& sub) {
    std::string result = str;
    size_t pos;

    // Find the substring in the string and erase it
    while ((pos = result.find(sub)) != std::string::npos) {
        result.erase(pos, sub.length());
    }

    return result;
}

void controlVolume(int value) {
    std::string command;
    if(value < -AXIS_DEADZONE) {
        command = "amixer sset '" + audDevice + "',0 " + std::to_string(VOLUME_STEP_SIZE) + "+";
    } else if(value > AXIS_DEADZONE) {
        command = "amixer sset '" + audDevice + "',0 " + std::to_string(VOLUME_STEP_SIZE) + "-";
    } else {
        command = "amixer sset '" + audDevice + "',0 0+";
    }

    // Execute the command and handle the output
    FILE* pipe = popen(command.c_str(), "r");
    if(!pipe) return;

    char buffer[128];
    std::string result = "";
    while(fgets(buffer, 128, pipe) != NULL) {
        result += buffer;
    }
    pclose(pipe);

	result = removeSubstring(result, "Playback");

	size_t pos = result.find("Limits:");
	if(pos != std::string::npos) {
        std::sscanf(result.c_str() + pos, "Limits: %d - %d", &VOLUME_MIN, &VOLUME_MAX);
    } else {
		
	}
	VOLUME_STEP_SIZE = (VOLUME_MAX - VOLUME_MIN) / 100;
	
    // Parse the output to find the current volume level
    pos = result.find("Front Left:");
    int currVol = 0;
    if(pos != std::string::npos) {
        std::sscanf(result.c_str() + pos, "Front Left: %d", &currVol);
    } else {
		pos = result.find("Mono:");
		if(pos != std::string::npos) {
			std::sscanf(result.c_str() + pos, "Mono: %d", &currVol);
        }
	}
	last_vol = currVol;
}

bool joyCheck(ControllerData controllers[], int c) {
	bool selectPressed = controllers[c].button_states[SELECT_BUTTON];
    bool startPressed  = controllers[c].button_states[START_BUTTON];

	bool optionsPressed = controllers[c].button_states[OPTIONS_BUTTON]; 
	
    bool rPressed      = controllers[c].button_states[R_BUTTON];
    bool lPressed      = controllers[c].button_states[L_BUTTON];
    bool yPressed      = controllers[c].button_states[Y_BUTTON];
    bool xPressed      = controllers[c].button_states[X_BUTTON];
    bool bPressed      = controllers[c].button_states[B_BUTTON];
    bool aPressed      = controllers[c].button_states[A_BUTTON];
	
    int axisValue = 0;
	if(controllers[c].button_states[DPAD_UP]){
		axisValue = -128;
	}
	if(controllers[c].button_states[DPAD_DOWN]){
		axisValue = 128;
	}
	
	
	if(optionsPressed && aPressed && rPressed && lPressed) {
		special_counter++;
		//std::cout << special_counter << std::endl;
		if(special_counter >= 1000) {
			//REBOOT
		    sync(); // Flush filesystem buffers
            std::string command;
			command = "reboot";

			// Execute the command and handle the output
			FILE* pipe = popen(command.c_str(), "r");
			if(pipe){
				char buffer[128];
				while(fgets(buffer, 128, pipe) != NULL) {
				}
				pclose(pipe);
			}
			//reboot(RB_AUTOBOOT);
			exit(0);
		}
		return true;
	} else if(optionsPressed && bPressed && rPressed && lPressed) {
		special_counter++;
		if(special_counter >= 1000) {
	        sync(); // Flush filesystem buffers
            std::string command;
			command = "shutdown -h now";

			// Execute the command and handle the output
			FILE* pipe = popen(command.c_str(), "r");
			if(pipe){
				char buffer[128];
				while(fgets(buffer, 128, pipe) != NULL) {
				}
				pclose(pipe);
			}
			//reboot(RB_POWER_OFF);
			exit(0);
		}
        return true;
	}
	else if(optionsPressed && xPressed && rPressed && lPressed) {
		special_counter++;
		if(special_counter == 1000) {
	        std::string command;
			command = "systemctl restart fbcp";

			// Execute the command and handle the output
			FILE* pipe = popen(command.c_str(), "r");
			if(pipe){
				char buffer[128];
				while(fgets(buffer, 128, pipe) != NULL) {
				}
				pclose(pipe);
			}
		}
        return true;
	}

	
	if(optionsPressed && bPressed) {
		if(special_counter == 0) {
			std::cout << "OVERLAY BATTERY " << manager.getBatteryAverage() << std::endl;
			overlay_id = OVERLAY_BATTERY;
			overlay_counter = 0;
		    special_counter++;
		}
        return true;
	} 
	//else if(selectPressed && aPressed && axisValue != 0) {
	//	int start_delay = 1000;
	//	int cont_delay = 100;
	//	if(special_counter == 1) {
	//		controlFan(axisValue);
	//		overlay_id = 2;
	//		overlay_counter = 0;
	//	}
	//	special_counter++;
	//	if(special_counter == start_delay) {
	//		controlFan(axisValue);
	//		overlay_id = 2;
	//		overlay_counter = 0;
	//	}
	//	if(special_counter >= (start_delay + cont_delay)) {
	//		special_counter = start_delay - 1;
	//	}
    //    return true;
	//} //not using a fan!
	//else if(selectPressed && aPressed) {
	//	if(special_counter == 0) {
	//		overlay_id = 2;
	//		overlay_counter = 0;
	//	}
	//	special_counter = 1;
    //    return true;
	//} 
	else if(optionsPressed && xPressed && axisValue != 0) {
		int start_delay = 1000;
		int cont_delay = 100;
		if(special_counter == 1) {
			std::cout << "OVERLAY VOLUME " << axisValue << std::endl;
			controlVolume(axisValue);
			overlay_id = OVERLAY_VOLUME;
			overlay_counter = 0;
		}
		special_counter++;
		if(special_counter == start_delay) {
			std::cout << "OVERLAY VOLUME " << axisValue << std::endl;
			controlVolume(axisValue);
			overlay_id = OVERLAY_VOLUME;
			overlay_counter = 0;
		}
		if(special_counter >= (start_delay + cont_delay)) {
			special_counter = start_delay - 1;
		}
        return true;
    } else if(optionsPressed && xPressed) {
		if(special_counter == 0) {
			std::cout << "OVERLAY VOLUME " << axisValue << std::endl;
			overlay_id = OVERLAY_VOLUME;
			overlay_counter = 0;
		}
		special_counter = 1;
        return true;
	} else if(optionsPressed && yPressed && axisValue != 0) {
		int start_delay = 1000;
		int cont_delay = 100;
		if(special_counter == 1) {
			std::cout << "OVERLAY BRIGHTNESS " << axisValue << std::endl;
			controlBrightness(axisValue);
			overlay_id = OVERLAY_BRIGHTNESS;
			overlay_counter = 0;
		}
		special_counter++;
		if(special_counter == start_delay) {
			std::cout << "OVERLAY BRIGHTNESS " << axisValue << std::endl;
			controlBrightness(axisValue);
			overlay_id = OVERLAY_BRIGHTNESS;
			overlay_counter = 0;
		}
		if(special_counter >= (start_delay + cont_delay)) {
			special_counter = start_delay - 1;
		}
        return true;
    } else if(optionsPressed && yPressed) {
		if(special_counter == 0) {
			std::cout << "OVERLAY BRIGHTNESS " << axisValue << std::endl;
			overlay_id = OVERLAY_BRIGHTNESS;
			overlay_counter = 0;
		}
		special_counter = 1;
        return true;
	}
	
	special_counter = 0;
	if(optionsPressed){
		return true;
	}
	return false;
}

#define DRAW_LOW_VOLTAGE 1

void drawOverlay(){
	overlay.clearScreen();
	switch(overlay_id){
		case OVERLAY_BATTERY: //Battery
			drawBatteryOverlay(manager.getBatteryAverage());
		    break;
		case OVERLAY_VOLUME: //Volume
			drawVolumeOverlay(0, last_vol);
		    break;
		case OVERLAY_FAN: //Fan
			drawFanOverlay(manager.fanValue, 0);
		    break;
		case OVERLAY_BRIGHTNESS: //Brightness
			drawBacklightOverlay(manager.backlightValue, 0);
		    break;
	}
	if(DRAW_LOW_VOLTAGE && batteryVoltage < 3.4){
		overlay.drawString("LOW VOLTAGE, PLEASE CHARGE", 4, 4, 0x8800, 0xF0);
	}

	if(DEBUG_GPIO_OVERLAY){
		render_pin_states();
	}
	overlay.commit();
}

int strcmp(std::string a, std::string b){
	return strcmp(a.c_str(), b.c_str());
}

#define HOLD_DELAY 100
int holdCounter = 0;
int getHeldPin(int pins[]){
	bool pinStates[25];
	bool search = true;
	int pin = 0, pinIndex = 0;
	holdCounter = 0;
	
	for(int i = 0; i < 25; i++){ //Get initial states
		if(pins[i] == 0) break;
		pinStates[i] = gpio.readPin(pins[i]);
	}
	
	while(search){
		for(int i = 0; i < 25; i++){
			if(pins[i] == 0) break;
			if(pinStates[i] != gpio.readPin(pins[i])){
				pinIndex = i;
				holdCounter++;
				if(holdCounter > HOLD_DELAY){
					pin = pins[i];
					search = false;
				}
			}
		}
		if(pinIndex > -1 && (pinStates[pinIndex] == gpio.readPin(pins[pinIndex]))){
			holdCounter = 0;
			pinIndex = -1;
		}
        std::this_thread::sleep_for(std::chrono::milliseconds(10));
	}
	
	std::cout << pin << "\n" << "Let Go to Continue" << std::flush;
	while(pinStates[pinIndex] != gpio.readPin(pins[pinIndex])){}
	
    std::this_thread::sleep_for(std::chrono::milliseconds(100));
	
	return pin;
}

int getHeldButton(){
	bool buttonStates[32];
	bool search = true;
	int buttonIndex = -1;
	holdCounter = 0;
	
	for(int i = 0; i < 32; i++){ //Get initial states
		buttonStates[i] = manager.controllers[0].button_states[i];
	}
	
	while(search){
		for(int i = 0; i < 32; i++){
			if(buttonStates[i] != manager.controllers[0].button_states[i]){
				buttonIndex = i;
				holdCounter++;
				if(holdCounter > HOLD_DELAY){
					search = false;
				}
			}
		}
		if(buttonIndex > -1 && (buttonStates[buttonIndex] == manager.controllers[0].button_states[buttonIndex])){
			holdCounter = 0;
			buttonIndex = -1;
		}
        std::this_thread::sleep_for(std::chrono::milliseconds(10));
	}
	
	std::cout << buttonIndex << "\n" << "Let Go to Continue" << std::flush;
	while(buttonStates[buttonIndex] != manager.controllers[0].button_states[buttonIndex]){}
	
    std::this_thread::sleep_for(std::chrono::milliseconds(100));
	
	return buttonIndex;
}
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
int main(int argc, char* argv[]) {
    std::cout << "Xemplar PicoTroller v" << VERSION << std::endl;
	
	Properties config;
	config.load(getLocalFile("config.prop"));
	config.addWhenMissing(true);
	audDevice               = config.get("audioDevice", ""); //Could be PCM, Headphone, or maybe something else
	bool initialized        = config.getBool("initialized", false);
	std::string monitorType = config.get("monitor", ""); //0 for unset, 1 for pico, 2 for gpio
    std::string interface   = config.get("interface", "/dev/serial0"); // normally /dev/serial0
	
	SELECT_BUTTON = config.getInt("BUTTON_SELECT", -1);
	START_BUTTON  = config.getInt("BUTTON_START", -1);
	L_BUTTON = config.getInt("BUTTON_L", -1);
	R_BUTTON = config.getInt("BUTTON_R", -1);

	// proper controllerrr
	A_BUTTON = config.getInt("BUTTON_A", -1);
	B_BUTTON = config.getInt("BUTTON_B", -1);
	X_BUTTON = config.getInt("BUTTON_X", -1);
	Y_BUTTON = config.getInt("BUTTON_Y", -1);

	DPAD_UP = config.getInt("DPAD_UP", -1);
	DPAD_DOWN = config.getInt("DPAD_DOWN", -1);
	DPAD_LEFT = config.getInt("DPAD_LEFT", -1);
	DPAD_RIGHT = config.getInt("DPAD_RIGHT", -1);

	OPTIONS_BUTTON = config.getInt("BUTTON_OPTIONS", -1);
	EXTRA_BUTTON = config.getInt("BUTTON_EXTRA", -1);
	
	if(strcmp(monitorType, "") == 0){
		std::cout << "No monitor has been selected, please enter one of the following: gpio, pico (or leave blank to exit)" << std::endl;
		std::getline(std::cin, monitorType);
		
		if(strcmp(monitorType, "gpio") == 0 || strcmp(monitorType, "pico") == 0){
			config.set("monitor", monitorType); 
		} else {
			if(strcmp(monitorType, "") == 0){
				std::cout << "Exiting..." << std::endl;
				return 0;
			} else {
				std::cout << "Invalid option, exiting..." << std::endl;
				return 0;
			}
		}
	}
	
	if(strcmp(monitorType, "gpio") == 0 && 
				(config.getInt("PIN_SELECT", -1) == -1 || 
				 config.getInt("PIN_START",  -1) == -1 || 
				 config.getInt("PIN_UP",     -1) == -1 || 
				 config.getInt("PIN_DOWN",   -1) == -1 || 
				 config.getInt("PIN_LEFT",   -1) == -1 || 
				 config.getInt("PIN_RIGHT",  -1) == -1 || 
				 config.getInt("PIN_L",      -1) == -1 || 
				 config.getInt("PIN_R",      -1) == -1 || 
				 config.getInt("PIN_A",      -1) == -1 || 
				 config.getInt("PIN_B",      -1) == -1 || 
				 config.getInt("PIN_X",      -1) == -1 || 
				 config.getInt("PIN_Y",      -1) == -1)){
		
		
		if(!configureGPIOMonitor(&config)) return 0;
	}
	
	if(strcmp(monitorType, "gpio") == 0){
		monitor = new GpioMonitor(config);
	} else if(strcmp(monitorType, "pico") == 0){
		if(strcmp(interface, "") == 0){
			std::cout << "Serial interface must be defined before running pico monitor. Exiting..." << std::endl;
			return 0;
		}
		monitor = new PicoMonitor(interface);
	}
	
	//remove unnecessary write
	if(!initialized){
		config.setBool("initialized", true);
		config.flush();
	}
	
	manager.setMonitor(monitor);
	manager.initMonitor();

    std::thread controllerThread(controllerLoop);
	
	if(SELECT_BUTTON == -1 || 
		START_BUTTON == -1 || 
		    L_BUTTON == -1 || 
		    R_BUTTON == -1 || 
		    X_BUTTON == -1){
		
		if(!configurePicotroller(&config)) return 0;
	}
	
	if(strcmp(audDevice, "") == 0){
		configureAudio(&config);
	}
	
	controlVolume(0); //Obtains initial volume
	
	overlay.clearScreen();
	overlay.commit();

    // Main loop
    while(true) {
		if(overlay_counter > -1) overlay_counter++;
		if(overlay_counter >= OVERLAY_TIMEOUT) {
			overlay_id = -1;
			overlay_counter = -1;
			overlay.clearScreen();
			overlay.commit();
		}
		
		drawOverlay();
		//10 fps should be enough for overlay, no?
        std::this_thread::sleep_for(std::chrono::milliseconds(100));
    }

    controllerThread.join();  // Join the thread before exiting (not reached in this example)
    return 0;
}

std::string getLocalFile(const std::string& filename) {
    // Buffer to store the path of the executable
    char exePath[1024];
    ssize_t count = readlink("/proc/self/exe", exePath, sizeof(exePath));
    if (count == -1) {
        perror("readlink");
        return "";
    }
    exePath[count] = '\0'; // Null-terminate the path

    // Get the directory name of the executable
    std::string dirPath = dirname(exePath);

    // Construct the full file path
    std::string filePath = dirPath + "/" + filename;

    return filePath;
}

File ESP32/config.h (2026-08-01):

// Target definition
#define RG_TARGET_NAME             "ESP32-S3-DEVKIT"
#define RG_STORAGE_SDSPI_HOLD_CS
// Storage
#define RG_STORAGE_ROOT             "/sd"
#define RG_STORAGE_SDSPI_HOST       SPI3_HOST
#define RG_STORAGE_SDSPI_SPEED      SDMMC_FREQ_DEFAULT
// #define RG_STORAGE_SDMMC_HOST       SDMMC_HOST_SLOT_1
// #define RG_STORAGE_SDMMC_SPEED      SDMMC_FREQ_DEFAULT
// #define RG_STORAGE_FLASH_PARTITION  "vfs"

// Audio
#define RG_AUDIO_USE_INT_DAC        0   // 0 = Disable, 1 = GPIO25, 2 = GPIO26, 3 = Both
#define RG_AUDIO_USE_EXT_DAC        1   // 0 = Disable, 1 = Enable

// Video
#define RG_SCREEN_DRIVER            0   // 0 = ILI9341/ST7789
#define RG_SCREEN_HOST              SPI2_HOST
#define RG_SCREEN_SPEED             SPI_MASTER_FREQ_40M // SPI_MASTER_FREQ_80M
#define RG_SCREEN_BACKLIGHT         1
#define RG_SCREEN_WIDTH             320
#define RG_SCREEN_HEIGHT            240
//#define RG_SCREEN_ROTATION          0
#define RG_SCREEN_ROTATE            2
//#define RG_SCREEN_RGB_BGR           0x08
#define RG_SCREEN_VISIBLE_AREA      {0, 0, 0, 0}
#define RG_SCREEN_SAFE_AREA         {0, 0, 0, 0}
#define RG_SCREEN_INIT()                                                                                           \
    ILI9341_CMD(0xCF, 0x00, 0xc3, 0x30);                                                                         \
    ILI9341_CMD(0xED, 0x64, 0x03, 0x12, 0x81);                                                                   \
    ILI9341_CMD(0xE8, 0x85, 0x00, 0x78);                                                                         \
    ILI9341_CMD(0xCB, 0x39, 0x2c, 0x00, 0x34, 0x02);                                                             \
    ILI9341_CMD(0xF7, 0x20);                                                                                     \
    ILI9341_CMD(0xEA, 0x00, 0x00);                                                                               \
    ILI9341_CMD(0xC0, 0x1B);                 /* Power control   //VRH[5:0] */                                    \
    ILI9341_CMD(0xC1, 0x12);                 /* Power control   //SAP[2:0];BT[3:0] */                            \
    ILI9341_CMD(0xC5, 0x32, 0x3C);           /* VCM control */                                                   \
    ILI9341_CMD(0xC7, 0x91);                 /* VCM control2 */                                                  \
    ILI9341_CMD(0x36, 0xA8);          /* Memory Access Control  (0x20|0x80|0x08) */                       \
    ILI9341_CMD(0xB1, 0x00, 0x10);           /* Frame Rate Control (1B=70, 1F=61, 10=119) */                     \
    ILI9341_CMD(0xB6, 0x0A, 0xA2);           /* Display Function Control */                                      \
    ILI9341_CMD(0xF6, 0x01, 0x30);                                                                               \
    ILI9341_CMD(0xF2, 0x00); /* 3Gamma Function Disable */                                                       \
    ILI9341_CMD(0x26, 0x01); /* Gamma curve selected */                                                          \
    ILI9341_CMD(0xE0, 0x0F, 0x31, 0x2B, 0x0C, 0x0E, 0x08, 0x4E, 0xF1, 0x37, 0x07, 0x10, 0x03, 0x0E, 0x09, 0x00); \
    ILI9341_CMD(0xE1, 0x00, 0x0E, 0x14, 0x03, 0x11, 0x07, 0x31, 0xC1, 0x48, 0x08, 0x0F, 0x0C, 0x31, 0x36, 0x0F);


// Input
// Refer to rg_input.h to see all available RG_KEY_* and RG_GAMEPAD_*_MAP types
#define RG_GAMEPAD_ADC_MAP {\
    {RG_KEY_UP,    ADC_UNIT_1, ADC_CHANNEL_5, ADC_ATTEN_DB_11, 3072, 4096},\
    {RG_KEY_LEFT, ADC_UNIT_1, ADC_CHANNEL_6, ADC_ATTEN_DB_11, 1024, 3071},\
    {RG_KEY_DOWN,  ADC_UNIT_1, ADC_CHANNEL_5, ADC_ATTEN_DB_11, 1024, 3071},\
    {RG_KEY_RIGHT,  ADC_UNIT_1, ADC_CHANNEL_6, ADC_ATTEN_DB_11, 3072, 4096},\
}
#define RG_GAMEPAD_GPIO_MAP {\
    {RG_KEY_SELECT, .num = GPIO_NUM_16, .pullup = 1, .level = 0},\
    {RG_KEY_START,  .num = GPIO_NUM_17, .pullup = 1, .level = 0},\
    {RG_KEY_MENU,   .num = GPIO_NUM_18, .pullup = 1, .level = 0},\
    {RG_KEY_OPTION, .num = GPIO_NUM_8,  .pullup = 1, .level = 0},\
    {RG_KEY_A,      .num = GPIO_NUM_15, .pullup = 1, .level = 0},\
    {RG_KEY_B,      .num = GPIO_NUM_5,  .pullup = 1, .level = 0},\
}

// Battery
#define RG_BATTERY_DRIVER           1
#define RG_BATTERY_ADC_UNIT         ADC_UNIT_1
#define RG_BATTERY_ADC_CHANNEL      ADC_CHANNEL_3
#define RG_BATTERY_CALC_PERCENT(raw) (((raw) * 2.f - 3500.f) / (4200.f - 3500.f) * 100.f)
#define RG_BATTERY_CALC_VOLTAGE(raw) ((raw) * 2.f * 0.001f)


// Status LED
#define RG_GPIO_LED                 GPIO_NUM_38

// SPI Display (back up working)
#define RG_GPIO_LCD_MISO            GPIO_NUM_NC
#define RG_GPIO_LCD_MOSI            GPIO_NUM_45
#define RG_GPIO_LCD_CLK             GPIO_NUM_48
#define RG_GPIO_LCD_CS              GPIO_NUM_21
#define RG_GPIO_LCD_DC              GPIO_NUM_47
#define RG_GPIO_LCD_BCKL            GPIO_NUM_38
#define RG_GPIO_LCD_RST             GPIO_NUM_3
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

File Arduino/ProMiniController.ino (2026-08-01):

#define AXIS_DUD A0
#define AXIS_DRL A1
#define BUTTON_B 6
#define BUTTON_START 5
#define BUTTON_SELECT 4
#define BUTTON_A 2
#define BUTTON_MENU 7
#define BUTTON_Y 9
#define BUTTON_X 8
#define BUTTON_VOLUME 10
#define BUTTON_R 11
#define BUTTON_L 12
#define MODE_SWITCH 13
#define BACKLIGHT_PIN 3
#define BATTERY_PIN A2

struct Axis {
  int pins[4];
  int digital_times_on[4];
  int digital_times_off[4];
  boolean analog = false;
  int x, y;
  int prevX, prevY;
};

struct Controller {
  int id;
  int button_count;
  int axis_count;
  boolean plugged_in;

  boolean prev_states[16];
  boolean button_states[16];
  int button_times_on[16];
  int button_times_off[16];
  int button_pins[16];
  Axis axis[4];
};

volatile Controller controllers[2];
volatile int battVal, bacVal = 255;
volatile boolean charging, systemOn;

//#define TOTAL_SHUTDOWN A4
//#define CHARGE_PIN A5

#define REG_3V3 A5
#define REG_5V A4

#define LED_MAX_VALUE 64

#define DEBOUNCE_TIME 20000

#define DEBUG true

long long last_update = -DEBOUNCE_TIME;

#define LED_POWER_ON 1
#define LED_POWER_OFF 2
#define LED_BATTERYLOW 3

#define LED_CHARGING10 4
#define LED_CHARGING25 5
#define LED_CHARGING50 6
#define LED_CHARGING75 7
#define LED_CHARGINGFULL 8

#define BATTERY_FULL 643
#define BATTERY_EMPTY 496

volatile int ledState = LED_BATTERYLOW;
volatile int counter = 0, systemOn_counter;
unsigned long counter_stamp, alive_stamp;

#define counter_delay 1000

byte readBuffer[64];
int readIndex = 0;
boolean reading = false;
long startTime = 0;

#define SERIAL_READ_TIMEOUT 10000
#define ALIVE_TIMEOUT 20000


void calcDebouce();
void readControllers();
float getBatteryPercent();
int getBatteryRaw();
float getBatteryPercent();
void processCommand(int func, int value);
void readSerial();
void sendFullStateRaw(int c);
void add_crc(uint8_t* message, size_t length);
uint16_t crc16_ccitt_xmodem(const uint8_t* data, size_t length);
void sendFullState(int c);
void sendButtonEvent(int controller, int button, boolean state);
void setBrightness(int brightness);

bool enableRaspi;


void setup() {
  enableRaspi = true;

  pinMode(REG_3V3, OUTPUT);
  pinMode(REG_5V, OUTPUT);
  digitalWrite(REG_3V3, LOW);
  digitalWrite(REG_5V, LOW);
  pinMode(BATTERY_PIN, INPUT);
  pinMode(MODE_SWITCH, OUTPUT);
  digitalWrite(MODE_SWITCH, LOW);
  //Setup Controller 1 (0)
  controllers[1].plugged_in = true;
  controllers[1].axis_count = 0;

  int c0_buttons[14] = { AXIS_DUD, AXIS_DUD, AXIS_DRL, AXIS_DRL, BUTTON_A, BUTTON_B, BUTTON_X, BUTTON_Y, BUTTON_START, BUTTON_SELECT, BUTTON_MENU, BUTTON_VOLUME, BUTTON_R, BUTTON_L };
  controllers[1].button_count = 14;
  for (int i = 0; i < controllers[1].button_count; i++) {
    controllers[1].button_pins[i] = c0_buttons[i];
  }

  controllers[0].button_count = 8;
  controllers[0].axis_count = 1;
  controllers[0].button_states[0] = false;

  //Setup Controller Pins
  for (int c = 0; c < 2; c++) {
    controllers[c].id = c + 1;
    for (int i = 0; i < controllers[c].button_count; i++) {
      if (c != 0)
        pinMode(controllers[c].button_pins[i], INPUT);
    }
  }

  //pinMode(LED_PIN, OUTPUT);
  pinMode(BACKLIGHT_PIN, OUTPUT);
  //pinMode(CHARGE_PIN, INPUT);

  systemOn = true;
  setBrightness(255);

  //Serial1.setRX(0);
  //Serial1.setTX(1); //???
  Serial.begin(57600);

  


  pinMode(BACKLIGHT_PIN, OUTPUT);

  // TCCR2A: Fast PWM, non-inverting on OC2B (Pin 3)
  TCCR2A = _BV(COM2B1) | _BV(WGM21) | _BV(WGM20);

  // TCCR2B: Prescaler set to 32
  // CS21 and CS20 = 1
  TCCR2B = _BV(CS21) | _BV(CS20);
  //Serial.begin(9600);
  delay(100);
  if (!digitalRead(BUTTON_A) || !digitalRead(BUTTON_B) || !digitalRead(BUTTON_X) || !digitalRead(BUTTON_Y)) {
    
    digitalWrite(MODE_SWITCH, LOW);
    digitalWrite(REG_3V3, LOW);
    digitalWrite(REG_5V, HIGH);
    
  }
  else{
    digitalWrite(MODE_SWITCH, HIGH);
    digitalWrite(REG_3V3, HIGH);
    digitalWrite(REG_5V, LOW);
    enableRaspi = false;
  }
}
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

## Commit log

2026-08-01 Some files
    [config.txt]
2026-08-01 Add amixer and esp32
2026-08-08 Add images of PCB
2026-08-11 Added KiCad design Files
    [bom_gameboy.xls, freerouting.dsn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]
2026-08-13 added 3d files
    [DPADBody.step, DPADBodyTop.step, DPADPin.step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]
